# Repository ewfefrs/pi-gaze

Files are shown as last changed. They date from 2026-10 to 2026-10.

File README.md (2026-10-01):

# Pi-Gaze

Айтрекер на Raspberry Pi 5: ИК-камера над монитором следит за глазами, и курсор ПК идёт
туда, куда ты смотришь. Для ПК это обычная USB-мышь (CH9329), ставить на ПК ничего не нужно.

| Часть | Где | Проверка |
|---|---|---|
| Железо: тиски на монитор, бар с камерой и ИК-диодами, доработанный кейс Pi | [`hardware/`](hardware/README.md) | `hardware/check.sh` — контр-модель, 63 проверки |
| Программа: трекер глаз, калибровка, курсор | [`software/`](software/README.md) | `software/build_tests_windows.cmd` на ПК; на Pi тесты гоняет установщик |
| Решения и дизайн | [`docs/superpowers/specs/`](docs/superpowers/specs/) | — |

## Запуск с нуля

1. Напечатать и собрать железо: [`hardware/README.md`](hardware/README.md).
2. SD-карта: Raspberry Pi OS Lite 64-bit + файлы из `software/deploy/sdcard/` и папка
   `pigaze/` (= `software/`) в загрузочном разделе. Wi-Fi: вписать имя и пароль в
   `network-config` на карте (или подключить кабель).
3. Вставить карту, включить Pi. Первая загрузка сама соберёт и поставит программу и перезагрузится (~10 мин).
4. Сесть перед монитором и смотреть на курсор, пока идёт калибровка по 9 точкам. Дальше курсор
   следует за взглядом. Кнопка питания Pi: 1 нажатие — пауза, 2 нажатия — перекалибровка.

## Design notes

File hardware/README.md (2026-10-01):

# Pi-Gaze — железо (тиски + бар + готовый кейс RPi 5)

Айтрекер: Raspberry Pi 5 + Active Cooler + Camera Module 3 NoIR + 2 ИК-диода + CH9329.
Тиски садятся на верхнюю кромку монитора, бар с камерой — на шарнире сверху, готовый
кейс Pi висит «хвостом» прямо под задней губкой тисков.

**Проверено контр-моделью:** `./check.sh` → **63 проверки, 0 ошибок** (отчёт `check_report.txt`).

## Файлы

```
hardware/
  check.sh              полная пересборка + контр-модель (запускать это)
  check_pigaze.py       контр-модель (Python: trimesh + Manifold, реальный STL Pi 5)
  README.md             этот файл
  renders/              превью всех деталей и сборки (preview.py из cad-skill)
  enclosure/src/        OpenSCAD: clamp.scad (тиски), bar.scad (бар), pigaze.scad (сборка)
  enclosure/stl/        печатные детали pigaze_*.stl
  mount/case_mod.py     доработка ГОТОВОГО кейса (CadQuery + Manifold)
  mount/case_pigaze.stl, cover_pigaze.stl   кейс и крышка для печати
```
Старый кастомный бокс, его крышка, толкатель и старый чекер — в `enclosure/src/legacy/`,
`enclosure/stl/legacy/`; отклонённые «переходники» — в `mount/_obsolete/`. Ничего не удалено.

## Что было не так и что исправлено (аудит 2026-09-23)

Всё найдено измерениями по реальным STL (кейс, крышка, Pi 5 + кулер), не «на глаз».

| # | Ошибка | Исправление |
|---|---|---|
| 1 | Щель шлейфа в кейсе была на торце USB/Ethernet, а разъёмы CSI у Pi 5 — на ребре HDMI (X 5–14); щель к тому же **сливалась со средним USB-проёмом** | Щель — в SD-торце над кулером (Z 17.5–22.5), USB-проёмы не тронуты |
| 2 | Винты дока шли через дно под корпусами USB/RJ45 — **не подлезть** | Док — язычок на торце кейса, 2×M3 **сзади**, гайки в губке тисков |
| 3 | Кейс висел USB вверх: штекер (35–40 мм) упирался в маховик (13 мм) | Кейс висит **SD-торцом вверх**, USB/Ethernet смотрят вниз |
| 4 | **Передняя губа тисков не свисала** (`LIP_H = TOP_T`) — тиски не держали монитор | Губа свисает на 5 мм, мягкая прокладка по полосе контакта |
| 5 | В баре полость крыльев **срезала светоперегородки** ниже Z 15.5 (как раз на высоте ИК), а над крыльями они торчали 2-мм плавниками | Стенки отсека камеры — на всю высоту, плавники убраны |
| 6 | Бортики и прижимы крышки бара **не были сращены** с плитой (лишь касались) — висели отдельными телами | Заходят в плиту на 0.5 мм, деталь — одно тело |
| 7 | Глухая крышка кейса в 8 мм над турбиной кулера — **кулер задыхается** | Решётка в крышке над турбиной (4 щели 3×28) |
| 8 | Шлейф шёл открыто; щели бара 12 мм, а кабель Pi 5 — **16 мм** | Шлейф по прямой в закрытом тоннеле внутри губки + паз под крышкой; щель бара 16.4 мм |
| 9 | Гайка барашка в **полностью замкнутом** кармане — не вставить | Карман открыт на внутреннюю грань губки |
| 10 | Карман гайки дока заходил в скругление губки (стенка ~0.6 мм) | Винты дока перенесены внутрь (X 14.5 / 21.5) |
| 11 | Паузы для магнитов в README указывали **дно** кармана (15.6 / 0.8 мм) | Верные: бар **17.6 мм**, крышка бара **2.8 мм** |
| 12 | Спецификация/сборка/проверка описывали старый бокс (втулки M2.5, 16 магнитов, толкатель) | Всё переписано под готовый кейс |
| 13 | CH9329 остался без места | Люлька на боковой (GPIO) стенке кейса + щель под провода |
| 14 | Наши добавки к кейсу «висели» (стенка торца на X −47, а не −48) и не были герметичны | Врастают в стенку на 1 мм; финальный STL проверяется после перезагрузки |

## Печать

| Деталь | Файл | Материал | На стол | Пауза (магниты) |
|---|---|---|---|---|
| Тиски | `enclosure/stl/pigaze_clamp.stl` | PETG/ASA, 4 стенки, 35% | **на боку** (грань −X на стол), брим; поддержка-дерево только под тумбой шарнира и бобышкой барашка | — |
| Крышка паза шлейфа | `pigaze_ribbon_cover.stl` | PETG | плашмя | — |
| Бар | `pigaze_bar.stl` | **чёрный** PETG | оптикой вниз | **17.6 мм** — 4 магнита |
| Крышка бара | `pigaze_bar_lid.stl` | **чёрный** PETG | наружной гранью вниз | **2.8 мм** — 4 магнита |
| Маховик Ø20 | `pigaze_knob.stl` | PETG | плашмя | — |
| Пятка | `pigaze_foot.stl` | TPU / PETG | площадкой вниз | — |
| Прокладка губы | `pigaze_pad.stl` | **TPU** | плашмя | — |
| Кейс | `mount/case_pigaze.stl` | PETG/ASA | **дном вниз** (как оригинал) | — |
| Крышка кейса | `mount/cover_pigaze.stl` | PETG/ASA | наружной гранью вниз | — |

* Тиски — **не PLA** (постоянная нагрузка, ползучесть). На боку тоннель и паз печатаются без поддержек.
* Кейс: все добавки стоят на плоскости стола или на откосах ≤50° — поддержки не нужны.
* Бар — только **чёрный** пластик: стенки не должны отражать ИК.
* Магниты: на паузе кладёшь в открытые карманы, печать их замуровывает. Полярность
  бар/крышка — противоположная, пометь маркером заранее.

## Закупка

| Позиция | Кол-во | Куда |
|---|---|---|
| Болт **M3×40** DIN933 (шестигр. головка) | 1 | барашек (головка в маховике) |
| Винт **M3×30** | 1 | ось шарнира + фиксация угла |
| Винт **M3×12** DIN912 (внутр. шестигр.) | 2 | док: язычок кейса → губка тисков |
| Винт **M3×6** (не длиннее! иначе конец упрётся в монитор) | 2 | крышка паза шлейфа |
| Гайка **M3** DIN934 | 6 | барашек 1 · шарнир 1 · док 2 · крышка паза 2 |
| Винт **M2.5×8** + гайка M2.5 | 4 + 4 | Pi → стойки кейса (гайки в шестигр. гнёзда снизу) |
| Магнит N42 **5×2 мм** | 8 | бар 4 + крышка бара 4 |
| Кабель камеры **Pi 5, 22→15 pin, 200 мм** (300 мм тоже влезет — излишек сложить под крышкой) | 1 | маршрут ≈163 мм |

Электроника: Pi 5 + Active Cooler · Camera Module 3 **NoIR** · 2× Vishay TSHA5203 (875 нм) +
2× 180 Ω + ключ-транзистор (диоды от 5 В, **не** напрямую от GPIO; база через ~1 кОм на
**GPIO18**, контакт 12 — им управляет программа) · модуль CH9329. Распиновка — в
[`software/README.md`](../software/README.md#подключение-pi-5-40-pin).

## Сборка

1. **Гайки:** в тисках — гайка барашка и 2 гайки дока в карманы на **внутренней** грани
   задней губки; 2 гайки крышки паза — снизу в карманы перемычки, **вдавить до упора вверх**; гайка шарнира — в правую щёку вилки бара.
2. **Pi в кейс** (4× M2.5×8 + гайки снизу). Кабель камеры узким концом (22 pin) — в CAM/DISP.
3. **Шлейф внутри:** плоско вдоль стороны HDMI к SD-торцу, над кулером (под крышкой ~7 мм зазора),
   и наружу через щель в торце. Провода ИК — рядом со шлейфом.
4. **Вверх по губке:** широкий конец кабеля продеть снизу в тоннель задней губки — он прямой,
   48 мм, выходит на верх перемычки.
5. **Док:** кейс язычком к наружной грани губки, 2× M3×12 **сзади** шестигранником через колодцы.
   Кейс снимается так же сзади, не снимая тиски.
6. Шлейф — в паз по верху перемычки, сверху **крышка паза** (2× M3×6; гайки снизу вталкиваются вверх до упора).
7. **Бар:** камера в карман, шлейф снизу через центральную щель в разъём камеры; ИК-диоды в
   колодцы, провода — через отверстия в стенке отсека; крышка бара на магнитах.
8. **Шарнир:** вилка бара на кулак, M3×30 + гайка, выставить угол (рабочий −20…−48°), затянуть.
9. **CH9329** в люльку на боку кейса; 4 провода от GPIO (контакты 1–10, со стороны SD) через щель.
   ⚠ Линии UART к Pi — только **3.3 В** (питай модуль от 3.3 В или ставь преобразователь уровней).
10. Крышка кейса на защёлку — решёткой к турбине кулера.
11. **На монитор:** передняя губа с TPU-прокладкой за переднюю рамку (≥5 мм рамки сверху),
    барашком прижать пятку к задней стенке.

## Контр-модель (`./check.sh`)

Пересобирает кейс, экспортирует все детали и позы и пытается доказать, что сборка плохая.
Последний прогон — **63/63**:

- **A** каждая деталь герметична и состоит из **одного** тела (ничего не «висит»);
- **B** попарные пересечения всех деталей в собранном виде — нет;
- **C** реальный Pi 5 + кулер внутри кейса/крышки — только посадка платы на стойки; выше всего
  стек USB (Z 21.6) — 2.4 мм до крышки;
- **D** «призрак» шлейфа 16.2 мм по всему маршруту (кейс → щель → воротник → тоннель → паз →
  подъём → щель бара) ни за что не задевает, в том числе за реальный Pi;
- **E** монитор 15 мм входит; губа реально цепляет рамку;
- **F** бар с крышкой на −20/−30/−38/−48° не задевает тиски, крышку паза, её винты, маховик, кейс;
- **G** маховик в крайних положениях не задевает кейс; место для пальцев 8.1 / 15 мм;
- **H** свободны штекеры RJ45, 2×USB, USB-C, 2×micro-HDMI, доступ к microSD и рычагу кнопки питания;
- **I** отверстия дока совпадают с гайками губки до 0.01 мм; щель кейса — в створе тоннеля;
  шарнир — на линии шлейфа;
- **J** щупы: стенки отсека бара на высоте ИК, нет плавников, карманы гаек доступны, тоннель сквозной;
- **K** зазор решётки кулера до монитора 15.5 мм; длина кабеля;
- **L** крепёж: конец винта крышки паза (M3×6) остаётся внутри перемычки (Z 1.0 над монитором), гайка
  навинчена на всю высоту; винты дока M3×12 проходят гайку губки и не достают до монитора.

## Что проверить на месте

* **Размер CH9329** — люлька под 34×15×9 мм (`CH_*` в `case_mod.py`), у модулей бывает иначе.
* **Рамка монитора** сверху ≥5 мм (губа свисает на 5 мм); толщина кромки — до ~27 мм.
* Какой разъём CAM/DISP используешь — неважно, маршрут общий.

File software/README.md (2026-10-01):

# Pi-Gaze — программа

Глаза двигают курсор ПК. Raspberry Pi 5 смотрит на глаза через ИК-камеру на баре, понимает,
куда на экране ты смотришь, и двигает мышь ПК через CH9329 (для ПК это обычная USB-мышь).
На ПК ничего ставить не надо.

Архитектура и решения: [`docs/superpowers/specs/2026-09-25-pigaze-software-design.md`](../docs/superpowers/specs/2026-09-25-pigaze-software-design.md).

## Как пользоваться

| Действие | Что происходит |
|---|---|
| Первое включение | Pi сам собирает и ставит программу (~5–10 мин, нужен интернет), перезагружается |
| Сел перед монитором | через 2 с видимых глаз стартует **калибровка**: курсор по очереди встаёт в 9 точек — **смотри на курсор** (~19 с) |
| Удачная калибровка | курсор описывает кружок в центре; дальше курсор ходит за взглядом |
| Неудачная | курсор «трясёт головой» влево-вправо; старая калибровка остаётся |
| Кнопка питания Pi, **1 нажатие** | пауза / продолжить (в паузе мышь снова твоя) |
| Кнопка питания, **2 нажатия** | перекалибровка (сдвинулся, пересел, сменил освещение) |
| Кнопка питания, **держать** | выключение Pi |

Моргание и взгляд мимо экрана курсор не дёргают — он просто стоит. Клик взглядом
(задержка на месте 1,2 с) выключен по умолчанию: `dwell_click = 1` в конфиге.

## С ПК по SSH

```bash
ssh -i ~/.ssh/pigaze_ed25519 -L 8080:localhost:8080 pigaze@pigaze.local
```

Пока сессия открыта, отладочная страница — <http://localhost:8080>: живой ИК-кадр
(жёлтое — окна глаз, красное — зрачок, зелёное — блики диодов), увеличенные глаза,
состояние и кнопки «Калибровка» / «Пауза». Страница слушает только localhost Pi,
потому что показывает твоё лицо.

На Pi:

```bash
journalctl -u pigaze -f            # лог: к/с, % кадров с глазами, режим, взгляд
pigaze-ctl calibrate               # toggle | pause | resume
sudo nano /etc/pigaze/pigaze.conf  # настройки, затем: sudo systemctl restart pigaze
pigaze --snapshot /tmp/f.pgm       # один кадр с камеры (при остановленной службе)
pigaze --selftest                  # проверка трекера на синтетике, без камеры
```

Пароля у пользователя `pigaze` нет — вход только по SSH-ключу. Нужен пароль для
консоли: `sudo passwd pigaze`.

## Настройка по месту

* **Фокус.** `lens_position = 1.7` — это 60 см (диоптрии = 1 / метры). Сидишь на 50 см → 2.0,
  на 70 см → 1.4. Смотри на увеличенные глаза на отладочной странице: зрачок должен быть резким.
* **Экспозиция.** По умолчанию авто. Если блики не белые или зрачок не чёрный:
  `shutter_us = 8000`, `gain = 4` и подстрой.
* **Очки** дают большие блики; они отфильтровываются (`glint_max_area`), но могут закрыть зрачок.
  Помогает наклон бара, чтобы отражение ушло вбок.
* **Курсор дрожит** → уменьши `filter_min_cutoff` (0.4). **Отстаёт** → увеличь `filter_beta` (3–4).

## Сборка и тесты

На Pi это делает установщик (`deploy/pi-setup.sh`): ставит `g++`, если нет, собирает, гоняет
модульные тесты и `--selftest`, ставит службу. Повторный запуск безопасен:

```bash
sudo bash /opt/pigaze/src/deploy/pi-setup.sh
```

На Windows-ПК (MSVC из Visual Studio) собираются и проверяются переносимые модули:

```bash
software/build_tests_windows.cmd
```

## Устройство

```
include/pigaze/, src/core/   переносимое ядро (тестируется на ПК и на Pi)
  eye_detector   зрачок (тёмный) + блики ИК-диодов в окне глаза, субпиксельный центр
  tracker        поиск пары глаз по бликам во всём кадре, слежение, моргания
  gaze           вектор «зрачок - блик» / межзрачковое расстояние -> полином 2-й степени
  calibration    9 точек курсором, медианы, проверка RMS
  filter         One Euro (без дрожи на фиксации, без задержки на скачках), dwell
  controller     режимы: нужна калибровка / калибровка / слежение / пауза
  ch9329         кадры протокола CH9329, абсолютная мышь 0..4095
  config, debugview, synth, image, linalg
src/linux/        rpicam-vid (кадры через pipe), UART, кнопка питания, FIFO, HTTP
src/main.cpp      сборка всего в цикл
deploy/           systemd-службы, установщик, logind (кнопка питания), pigaze-ctl
```

## Подключение (Pi 5, 40-pin)

| Pi | Куда |
|---|---|
| pin 1 (3.3 V) | CH9329 VCC (модуль на 3.3 В — тогда и его TX 3.3 В, безопасно для Pi) |
| pin 6 (GND) | CH9329 GND |
| pin 8 (GPIO14, TX) | CH9329 **RX** |
| pin 10 (GPIO15, RX) | CH9329 **TX** |
| pin 12 (GPIO18) | база ключ-транзистора ИК-диодов (через ~1 кОм) |
| pin 2/4 (5 V) | питание ИК-диодов через 180 Ω |

USB CH9329 — в ПК. Камера — в любой из разъёмов CAM/DISP.

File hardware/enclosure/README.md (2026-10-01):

# Pi-Gaze enclosure (OpenSCAD part of the hardware)

See **../README.md** (build, print, BOM, assembly) and run **../check.sh** (full rebuild + counter-model).
The retired custom-box design and its old README live in `src/legacy/`.

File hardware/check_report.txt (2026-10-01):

[A] printable parts: watertight + one solid body
  PASS  A clamp                                        watertight=True solids=1
  PASS  A ribbon_cover                                 watertight=True solids=1
  PASS  A pad                                          watertight=True solids=1
  PASS  A foot                                         watertight=True solids=1
  PASS  A knob                                         watertight=True solids=1
  PASS  A bar                                          watertight=True solids=1
  PASS  A bar_lid                                      watertight=True solids=1
  PASS  A case                                         watertight=True solids=1
  PASS  A cover                                        watertight=True solids=1

[B] pairwise interference (assembled, bar at -38 deg)
  PASS  B bar <-> bar_lid                              overlap 0.000 mm3
  PASS  B case<->cover (stock snap fit)                INFO overlap 0.00 mm3 (original cover design)
  PASS  B all other pairs                              no overlap

[C] real Pi 5 + Active Cooler inside the modified case / cover
  PASS  C Pi vs case (excl. PCB-on-standoff contact)   3 pts inside (437 standoff contact)
  PASS  C Pi vs cover                                  0 pts inside
  PASS  C tallest Pi part under the cover              top Z 21.62, cover underside 24.03

[D] ghost camera ribbon (16.2 mm) along the full route
  PASS  D ribbon: inside case -> slot -> collar -> jaw tunnel worst: clamp 0.000 mm3
  PASS  D ribbon: bridge-top groove (under cover)      worst: clamp 0.000 mm3
  PASS  D ribbon: free rise to the bar                 worst: clamp 0.000 mm3
  PASS  D ribbon: through the bar floor slot (bar -38 deg) worst: clamp 0.000 mm3
  PASS  D ribbon run under the cover vs real Pi        0 Pi points in the ribbon's path
  PASS  K camera cable route length                    163 mm -> use the 200 mm Pi 5 camera cable (300 mm also fits, fold slack under the cover)

[E] monitor fit (top edge 15 mm)
  PASS  E monitor <-> clamp                            overlap 0.000 mm3
  PASS  E monitor <-> pad                              overlap 0.000 mm3
  PASS  E monitor <-> foot                             overlap 0.000 mm3
  PASS  E monitor <-> case                             overlap 0.000 mm3
  PASS  E monitor <-> cover                            overlap 0.000 mm3
  PASS  E monitor <-> ribbon_cover                     overlap 0.000 mm3
  PASS  E monitor <-> knob                             overlap 0.000 mm3
  PASS  E front lip hangs below the monitor top        lip bottom Z -5.0 (monitor top at 0)

[F] hinge sweep -20..-48 deg
  PASS  F bar+lid at -20 deg                           worst: - 0.000 mm3
  PASS  F bar+lid at -30 deg                           worst: - 0.000 mm3
  PASS  F bar+lid at -38 deg                           worst: - 0.000 mm3
  PASS  F bar+lid at -48 deg                           worst: - 0.000 mm3

[G] thumbscrew knob travel
  PASS  G knob at Y=31 vs case/bar                     overlap 0.000 mm3
  PASS  G finger room knob(Y=31) -> case               min gap 8.2 mm (need 7)
  PASS  G knob at Y=45 vs case/bar                     overlap 0.000 mm3
  PASS  G finger room knob(Y=45) -> case               min gap 15.0 mm (need 10)
  PASS  G thumbscrew bolt vs case/cover                

[H] access: plugs, card, button
  PASS  H RJ45 plug (down) free                        blocked 0.000 mm3
  PASS  H USB stack 1 plug free                        blocked 0.000 mm3
  PASS  H USB stack 2 plug free                        blocked 0.000 mm3
  PASS  H USB-C power plug free                        blocked 0.000 mm3
  PASS  H micro-HDMI 0 plug free                       blocked 0.000 mm3
  PASS  H micro-HDMI 1 plug free                       blocked 0.000 mm3
  PASS  H microSD fingernail free                      blocked 0.000 mm3
  PASS  H power-button lever free                      blocked 0.000 mm3

[I] interfaces
  PASS  I dock hole case(-58,11.0) -> jaw nut X14      maps to X 14.50 Z -36.00
  PASS  I dock hole case(-58,18.0) -> jaw nut X22      maps to X 21.50 Z -36.00
  PASS  I case ribbon slot within jaw tunnel X         slot X -25.0..-8.0 / tunnel -25.5..-7.5
  PASS  I ribbon slot straddles tunnel Y               slot Y 18.0..23.0 / tunnel 19.0..22.0
  PASS  I hinge on the ribbon line                     hinge X -16.5

[J] probes
  PASS  J bar: compartment wall at IR height (+/-18.3,0,9) 
  PASS  J bar: no external fins (+/-20.5,0,22)         
  PASS  J thumbscrew nut pocket reachable from monitor side 
  PASS  J dock 1 nut pocket reachable from monitor side 
  PASS  J dock 2 nut pocket reachable from monitor side 
  PASS  J ribbon tunnel open bottom->top               

[L] fasteners: screw tips vs monitor, nut engagement
  PASS  L cover screw M3x6 tip stays inside the bridge tip Z 1.0 (monitor top at 0)
  PASS  L cover screw fully through its nut            engaged 2.4 / 2.4 mm
  PASS  L cover nut pocket reachable from below        
  PASS  L dock screw M3x12 through the jaw nut         tip Y 15.7, nut Y 17.0-19.4
  PASS  L dock screw tip clear of a 27 mm monitor      tip Y 15.7 vs monitor back Y 10.0

[K] cooling
  PASS  K fan-grille -> monitor back air gap           15.5 mm

COUNTER-MODEL CLEAN: 63 checks, 0 failures

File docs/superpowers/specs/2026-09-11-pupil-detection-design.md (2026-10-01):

# Pi-Gaze — Module 1: Pupil Detection (design)

- **Date:** 2026-09-11
- **Status:** SUPERSEDED by `2026-09-25-pigaze-software-design.md` (OpenCV + toolchain does not
  fit the 3.7 GB SD card; the IR glints make a face DNN unnecessary)
- **Author:** Claude (with user)

## Goal

Produce a reliable **per-frame pupil center (x, y) for each eye** from a remote,
monitor-mounted IR camera, verifiable **headless over SSH**. This is the input
foundation for later gaze mapping — it does not itself move a cursor.

## Context & constraints

- **Hardware:** Raspberry Pi 5, Camera Module 3 **NoIR**, IR illuminators, mounted
  on the bar at the monitor's top edge, tilted down at the user's face.
- **Geometry:** *remote* — the whole face is in frame at ~40–70 cm. So we must
  localize face → eyes **before** looking for the pupil (the pupil is only a few
  pixels wide at this distance).
- **Illumination:** IR (NoIR sensor + IR LEDs) gives a **dark-pupil** signal and
  bright **corneal glints** from the LEDs.
- **Software:** C++17 (real-time perf), OpenCV, Raspberry Pi OS Lite 64-bit
  (Bookworm), headless. Pi 5 camera stack is **libcamera** (not legacy V4L2).

## Scope

**In:** camera capture; face + eye localization; pupil center per eye; glint
position; per-result confidence; headless verification (annotated frame dump +
optional MJPEG stream); a small config file; FPS logging.

**Out (later modules, not now):** gaze mapping & calibration; CH9329 USB-HID mouse
output; control-loop smoothing/filtering; multi-user; auto IR power control.

## Architecture (units, each independently testable)

1. **Camera** — opens the Camera Module 3 through libcamera and yields grayscale
   `cv::Mat` frames. Path: OpenCV `VideoCapture` with the **GStreamer**
   `libcamerasrc` pipeline (`libcamerasrc ! video/x-raw ! videoconvert ! appsink`),
   the clean C++ route on Pi 5. Exposes manual exposure/gain for IR tuning.
2. **FaceEyes** — runs OpenCV's built-in **YuNet** DNN face detector
   (`cv::FaceDetectorYN`, mainline objdetect since 4.5.4). YuNet returns the face
   box **plus 5 landmarks including both eye centers**, so we get eye ROIs with no
   separate eye cascade and no heavy landmark model. Emits `std::vector<Eye>`.
3. **PupilDetector** — within an eye ROI: normalize → adaptive threshold on the
   **dark-pupil** region → contour extraction → filter by area/circularity →
   **ellipse fit** for a sub-pixel center; separately take the brightest spot as
   the IR **glint**. Emits a `PupilResult`.
4. **Telemetry/Verify** — a `PupilResult` sink: structured log (coords, radius,
   confidence, FPS), annotated-frame writer (JPEG to disk), and an optional MJPEG
   HTTP server so the result can be watched in a browser over SSH.
5. **Config** — a small file (key=value or minimal JSON): camera resolution/fps,
   exposure/gain, threshold/ROI-scale, output mode. Sane defaults if absent.
6. **App loop** — wires Camera → FaceEyes → PupilDetector → Telemetry; clean
   startup/shutdown, signal handling.

## Interfaces (sketch)

```cpp
struct PupilResult {
    cv::Point2f center;        // in full-frame coordinates
    float       radius;        // px (ellipse minor/major avg)
    float       confidence;    // 0..1
    std::optional<cv::Point2f> glint;
    bool        valid;
};
struct Eye { cv::Rect roi; cv::Point2f center; bool isLeft; };

class Camera        { public: bool open(const Config&); bool next(cv::Mat& gray); };
class FaceEyes      { public: bool load(const std::string& model); std::vector<Eye> detect(const cv::Mat& gray); };
class PupilDetector { public: PupilResult detect(const cv::Mat& gray, const Eye& eye); };
```

## Data flow

`frame → FaceEyes.detect → per-eye ROI → PupilDetector.detect → PupilResult[] → Telemetry`

## Error handling

- Camera/GStreamer open fails → clear message, non-zero exit.
- No face this frame → emit "no face", keep running (don't crash/stall).
- Low-confidence or no pupil → `valid=false`; never emit a garbage coordinate.
- Missing config → defaults; malformed config → warn + defaults for bad keys.

## Verification (headless, over SSH)

- **Golden test:** a handful of recorded IR eye frames are checked into
  `test/data/` with hand-labeled pupil centers; the detector must land within a
  pixel tolerance. Runs in CI-style `ctest` with no camera attached.
- **Live check:** annotated-frame dump + FPS counter; optional MJPEG to eyeball it
  in a browser.
- **Success criteria:** on a cooperative user at ~60 cm, pupil center jitter
  **< ~3 px** frame-to-frame, **≥ 15 FPS** at the chosen resolution, and graceful
  "no face"/`valid=false` handling when the eye is occluded or absent.

## Build & deploy

- **CMake** project under `pi-gaze/software/`. Dependencies from apt on Bookworm:
  `libopencv-dev` (has DNN + GStreamer), `gstreamer1.0-libcamera`,
  `libcamera-dev`. YuNet `.onnx` model vendored under `software/models/`.
- Build **on the Pi** (needs a **≥16 GB** card — the current 3.7 GB card fits the
  OS but not OpenCV + toolchain) or cross-compile. First bring-up can validate raw
  capture with `rpicam-hello` before OpenCV is present.

## Assumptions / open items (safe defaults chosen)

- Resolution/FPS start at **1280×720 @ 30**; revisit if the pupil is too small.
- Detect **both** eyes; downstream picks the higher-confidence one.
- IR exposure/gain set **manually** in config for v1 (no auto control yet).

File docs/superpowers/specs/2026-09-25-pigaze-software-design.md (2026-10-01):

# Pi-Gaze — software v1 (design)

- **Date:** 2026-09-25
- **Status:** approved by delegation ("продумай логику сам, доводи до ума")
- **Supersedes:** `2026-09-11-pupil-detection-design.md` (OpenCV + YuNet) — see "Why not OpenCV".

## Goal

Eyes move the PC cursor. The Pi watches the user's eyes through the IR camera on the
bar, estimates where on the screen they look, and moves the PC's mouse through the
CH9329 (USB HID). No software on the PC.

## Why not OpenCV (change from the 09-11 spec)

The only SD card is **3.7 GB**; Pi OS Lite 64-bit (Trixie) takes 3.06 GB, leaving ~0.9 GB.
OpenCV-dev + GStreamer + toolchain does not fit. The IR setup gives a much cheaper eye
finder than a face DNN: **corneal glints** (reflections of our own IR LEDs) are the
brightest tiny spots in the frame and each sits right next to a **dark pupil**. So the
whole pipeline is plain C++17 with no third-party libraries:

- camera frames come from `rpicam-vid --codec yuv420 -o -` (preinstalled rpicam-apps),
  we read the Y plane from the pipe;
- detection, calibration, filtering, HID, debug web page — our own code;
- the portable core (everything except camera/serial/button/http) builds and is
  unit-tested on the Windows PC with MSVC, and again on the Pi with g++ before install.

## Pipeline

```
rpicam-vid (Y plane) -> EyeTracker -> features -> GazeModel -> OneEuro -> Controller -> CH9329 -> PC cursor
                         |  finder: glint + dark pupil, pairs by IPD
                         |  tracker: per-eye ROI around last pupil
```

1. **EyeDetector** (per eye ROI): median/threshold -> glint blobs (small, bright) ->
   inpaint glints -> darkest seed (with distance penalty) -> region grow with an adaptive
   pupil/iris threshold (2 passes) -> moments -> radial edge points -> ellipse fit
   (fallback circle, fallback centroid) -> confidence. Glint = intensity-weighted centroid
   of the small bright blobs near the pupil (the two LED reflections are < 3 px apart at
   60 cm, so they are treated as one reference point).
2. **EyeFinder** (full frame, only when not tracking): bright small blobs with local
   contrast -> run EyeDetector around each -> dedupe -> choose the best **pair** whose
   distance fits the IPD range and is roughly horizontal. Initial acquisition requires a
   pair (so slot 0 = image-left eye, slot 1 = image-right eye is unambiguous).
3. **EyeTracker**: per slot ROI tracking; blink tolerance (`lost_frames`); re-acquires a
   single lost eye from the other eye + last inter-eye offset; full search when both lost.
   Keeps a smoothed IPD in px (head-distance scale).
4. **Feature** per eye: `(pupil - glint) * 100 / IPD_px` — pupil-centre/corneal-reflection
   vector normalised by head distance.
5. **GazeModel**: per eye 2nd-order polynomial (6 terms per axis, ridge LS; affine if < 6
   points), inputs normalised. Prediction = confidence-free mean of the valid eyes.
   Saved to `/var/lib/pigaze/calibration.txt`.
6. **Calibration without a PC app**: the Pi itself puts the cursor (CH9329 absolute mode)
   on 9 points (3x3, 10 % margin), wiggles it briefly to catch the eye, waits for the
   saccade to settle, collects ~1 s of features, takes per-point medians, fits, checks
   RMS. Success -> cursor draws a small circle; failure -> cursor shakes, old calibration
   is kept.
7. **Filtering**: One Euro filter (low jitter on fixations, low lag on saccades); cursor
   held still when no valid gaze (blink, looking away). Optional dwell click (off).
8. **Controller** modes: `NeedCalibration -> Calibrating -> Tracking <-> Paused`.
   Inputs: Pi 5 **power button** (logind told to ignore it): single press = pause/resume
   (or start calibration if none), double press = recalibrate; long press stays
   "power off" (logind `HandlePowerKeyLongPress=poweroff`). Also a FIFO
   `/run/pigaze/control` (`pigaze-ctl calibrate|toggle|pause|resume`) and the debug page.
   Auto-calibration on first run once eyes are seen for 2 s.
9. **CH9329**: UART0 on GPIO14/15 (`/dev/ttyAMA0`, 9600 8N1, `dtparam=uart0=on`),
   absolute mouse frames `57 AB 00 04 07 02 btn xl xh yl yh wh sum`, 0..4095 range.
   Moves are dropped (not queued) if the UART still has > 2 frames pending -> no lag build-up.
10. **Debug page** (`http_bind:http_port`, default `127.0.0.1:8080`, reach via
    `ssh -L 8080:localhost:8080`): live downscaled IR frame + eye zooms with the pupil/glint
    overlay (BMP, no encoder needed), JSON status, Calibrate / Pause buttons. Localhost by
    default because it shows the user's face.

## Files

```
software/
  include/pigaze/*.hpp      src/core/*.cpp   (portable, unit-tested on PC and Pi)
  src/linux/*.cpp  src/main.cpp              (rpicam pipe, termios, input, http, fifo)
  tests/*.cpp                                (own tiny harness, no downloads)
  config/pigaze.conf   deploy/ (systemd units, installer, logind drop-in, pigaze-ctl)
  CMakeLists.txt  build_tests_windows.cmd
```

## Deploy

SD card: Pi OS Lite 64-bit Trixie; cloud-init `user-data` creates user `pigaze`
(SSH **key only**, no password), hostname `pigaze`, enables SSH; `config.txt` gets
`dtparam=uart0=on`; the source is copied to the boot partition. On first boot a oneshot
service (retried every boot until it succeeds, needs network for `apt install g++`)
builds + runs the tests on the Pi, installs `/usr/local/bin/pigaze`, the config, the
service and the logind drop-in, then reboots once. Wi-Fi: the user types SSID/password
into `network-config` themselves, or plugs Ethernet.

## Error handling

- Camera missing / rpicam-vid exits -> logged, restarted every 3 s; service keeps running.
- CH9329 missing -> logged once; tracking still runs (debug page works), retried every 5 s.
- No eyes / low confidence -> no cursor movement, never a garbage coordinate.
- Bad config keys -> warning + default.

## Verification

- PC: `software/build_tests_windows.cmd` (MSVC) — detector accuracy on synthetic IR eyes
  (sub-pixel centre, glint on the pupil edge, eyelid, noise, no-eye rejection), finder
  on a synthetic face with distractors, tracker through a blink, polynomial fit,
  calibration session, One Euro, dwell, CH9329 bytes, config, controller modes, BMP.
- Pi: installer compiles and runs the same tests before installing; `pigaze --selftest`
  runs the synthetic scene through the live binary; `pigaze --snapshot f.pgm` grabs a
  real frame for tuning; debug page for live checks.

## Known limits (v1)

- Accuracy is that of a single-camera PCCR tracker: expect ~1–2 deg (1–2 cm at 60 cm);
  moving the head a lot calls for recalibration (double press).
- Absolute HID maps to the primary monitor on Windows.
- Glasses reflections: large bright blobs are ignored as glints, but can hide the pupil.

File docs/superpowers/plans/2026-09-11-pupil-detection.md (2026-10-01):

# Pupil Detection (Module 1) Implementation Plan

> **SUPERSEDED (2026-09-25):** not executed. Replaced by the dependency-free implementation in
> `software/` — see `docs/superpowers/specs/2026-09-25-pigaze-software-design.md`.

> **For agentic workers:** REQUIRED SUB-SKILL: Use superpowers:subagent-driven-development (recommended) or superpowers:executing-plans to implement this plan task-by-task. Steps use checkbox (`- [ ]`) syntax for tracking.

**Goal:** Detect a per-frame pupil center (x, y) for each eye from a remote, monitor-mounted IR camera, verifiable headless over SSH.

**Architecture:** A small C++17/CMake project under `pi-gaze/software/`. A `pigaze_core` library exposes independent units — Config, PupilDetector, Telemetry, FaceEyes, Camera — wired by a thin `pigaze` app. The pipeline is Camera → FaceEyes (YuNet) → PupilDetector (IR dark-pupil ellipse fit) → Telemetry. Camera-independent units are built and unit-tested first on any Linux dev box; the camera unit is brought up on the Pi.

**Tech Stack:** C++17, CMake, OpenCV (`libopencv-dev`, uses `objdetect`/`FaceDetectorYN`, `imgproc`, `dnn`, GStreamer capture), doctest (vendored single header), libcamera via OpenCV's GStreamer `libcamerasrc` backend.

## Global Constraints

- Language **C++17**; build **CMake ≥ 3.16**; compiler **g++ ≥ 10** or clang.
- **OpenCV ≥ 4.5.4** with `objdetect` (for `cv::FaceDetectorYN`), `imgproc`, `dnn`, and **GStreamer** capture — install via `apt install libopencv-dev` on Debian **Bookworm** (the Pi) or Ubuntu (a **WSL2** dev box; native Windows C++ OpenCV is out of scope).
- Test framework: **doctest**, vendored at `software/third_party/doctest.h`; one test binary `pigaze_tests` registered with **CTest**.
- All pupil/glint coordinates are in **full-frame pixel space** unless a signature says ROI-local.
- Camera capture uses **libcamera** through OpenCV `VideoCapture(pipeline, cv::CAP_GSTREAMER)` — never legacy V4L2.
- **TDD**: every unit lands with its failing test first. **Commit after every green step.**
- Build/run on the Pi needs a **≥ 16 GB** SD card (OpenCV + toolchain); the 3.7 GB card is OS-only.

## File Structure

```
software/
  CMakeLists.txt              # top-level: core lib + app + tests
  third_party/doctest.h       # vendored single-header test framework
  include/pigaze/
    types.hpp                 # PupilResult, Eye (POD, no logic)
    config.hpp                # Config struct + load()
    pupil_detector.hpp        # PupilDetector
    telemetry.hpp             # Telemetry (log/annotate/writeFrame)
    face_eyes.hpp             # FaceEyes (YuNet)
    camera.hpp                # Camera (libcamera/GStreamer)
  src/
    config.cpp
    pupil_detector.cpp
    telemetry.cpp
    face_eyes.cpp
    camera.cpp
    main.cpp                  # app loop
  models/                     # face_detection_yunet_2023mar.onnx (vendored)
  test/
    test_types.cpp
    test_config.cpp
    test_pupil_detector.cpp
    test_telemetry.cpp
    test_golden.cpp
    test_face_eyes.cpp
    fixtures.hpp              # synthetic-image helpers shared by tests
    data/                     # golden frames + labels, a test face image
  config.example.ini
```

Tasks 1–5 build and test with **no camera** (any Linux/WSL2). Task 6 needs the YuNet model + a face image (still no camera). Tasks 7–8 need the Pi + camera.

---

### Task 1: Project scaffold, types, and a green CTest

**Files:**
- Create: `software/CMakeLists.txt`, `software/third_party/doctest.h` (download), `software/include/pigaze/types.hpp`, `software/test/test_types.cpp`
- Test: `software/test/test_types.cpp`

**Interfaces:**
- Produces: `pigaze::PupilResult { cv::Point2f center; float radius; float confidence; std::optional<cv::Point2f> glint; bool valid; }` and `pigaze::Eye { cv::Rect roi; cv::Point2f center; bool isLeft; }`.

- [ ] **Step 1: Vendor doctest**

Run: `curl -L -o software/third_party/doctest.h https://raw.githubusercontent.com/doctest/doctest/v2.4.11/doctest/doctest.h`
Expected: file ~230 KB exists.

- [ ] **Step 2: Write the failing test**

`software/test/test_types.cpp`:
```cpp
#include "doctest.h"
#include "pigaze/types.hpp"

TEST_CASE("PupilResult default is invalid") {
    pigaze::PupilResult r;
    CHECK(r.valid == false);
    CHECK_FALSE(r.glint.has_value());
}
TEST_CASE("Eye holds an ROI and a side flag") {
    pigaze::Eye e{ cv::Rect(1, 2, 3, 4), cv::Point2f(2.5f, 4.0f), true };
    CHECK(e.roi.width == 3);
    CHECK(e.isLeft);
}
```

- [ ] **Step 3: Write `CMakeLists.txt` (core lib + tests)**

`software/CMakeLists.txt`:
```cmake
cmake_minimum_required(VERSION 3.16)
project(pigaze LANGUAGES CXX)
set(CMAKE_CXX_STANDARD 17)
set(CMAKE_CXX_STANDARD_REQUIRED ON)
find_package(OpenCV REQUIRED)
enable_testing()

add_library(pigaze_core)           # sources added by later tasks
target_include_directories(pigaze_core PUBLIC include ${OpenCV_INCLUDE_DIRS})
target_link_libraries(pigaze_core PUBLIC ${OpenCV_LIBS})
set_target_properties(pigaze_core PROPERTIES LINKER_LANGUAGE CXX)

add_executable(pigaze_tests
    test/test_types.cpp)
target_include_directories(pigaze_tests PRIVATE third_party include)
target_link_libraries(pigaze_tests PRIVATE pigaze_core)
add_test(NAME pigaze_tests COMMAND pigaze_tests)
```
Add a doctest main once, at the top of `test/test_types.cpp`:
```cpp
#define DOCTEST_CONFIG_IMPLEMENT_WITH_MAIN
```
(placed above the existing `#include "doctest.h"`).

`pigaze_core` needs at least one source to link; add a placeholder now and replace in Task 2:
```cmake
target_sources(pigaze_core PRIVATE src/placeholder.cpp)
```
Create `software/src/placeholder.cpp` with `namespace pigaze { int _link_stub = 0; }`.

- [ ] **Step 4: Write `types.hpp`**

`software/include/pigaze/types.hpp`:
```cpp
#pragma once
#include <optional>
#include <opencv2/core.hpp>
namespace pigaze {
struct PupilResult {
    cv::Point2f center{};
    float radius{0.f};
    float confidence{0.f};
    std::optional<cv::Point2f> glint{};
    bool valid{false};
};
struct Eye {
    cv::Rect roi{};
    cv::Point2f center{};
    bool isLeft{false};
};
}  // namespace pigaze
```

- [ ] **Step 5: Configure, build, run — expect PASS**

Run: `cmake -S software -B software/build && cmake --build software/build -j && ctest --test-dir software/build --output-on-failure`
Expected: `pigaze_tests` PASS (2 test cases).

- [ ] **Step 6: Commit**
```bash
git add software/ && git commit -m "feat(sw): scaffold CMake+doctest, core types"
```

---

### Task 2: Config loader

**Files:**
- Create: `software/include/pigaze/config.hpp`, `software/src/config.cpp`, `software/config.example.ini`, `software/test/test_config.cpp`
- Modify: `software/CMakeLists.txt` (add `src/config.cpp` to `pigaze_core`, delete the placeholder; add `test/test_config.cpp` to `pigaze_tests`)

**Interfaces:**
- Consumes: nothing.
- Produces: `struct Config { int width=1280, height=720, fps=30; double exposure=-1, gain=-1; int pupilBlockSize=31; double pupilC=10; double roiScale=1.6; std::string outputMode="jpeg"; std::string modelPath="models/face_detection_yunet_2023mar.onnx"; };` and `Config load(const std::string& path);` (missing file → all defaults; unknown/malformed lines → warn to stderr, keep defaults).

- [ ] **Step 1: Write the failing test**

`software/test/test_config.cpp`:
```cpp
#include "doctest.h"
#include "pigaze/config.hpp"
#include <fstream>

TEST_CASE("missing file yields defaults") {
    auto c = pigaze::load("definitely_absent.ini");
    CHECK(c.width == 1280);
    CHECK(c.fps == 30);
}
TEST_CASE("known keys override defaults; junk ignored") {
    const char* p = "test_cfg_tmp.ini";
    std::ofstream(p) << "width=640\nfps=60\nnonsense line\nroiScale=2.0\n";
    auto c = pigaze::load(p);
    CHECK(c.width == 640);
    CHECK(c.fps == 60);
    CHECK(c.roiScale == doctest::Approx(2.0));
    CHECK(c.height == 720);  // untouched default
    std::remove(p);
}
```

- [ ] **Step 2: Run to verify it fails**
Run: `cmake --build software/build -j` — expect compile error (`config.hpp` missing).

- [ ] **Step 3: Implement `config.hpp` + `config.cpp`**

`software/include/pigaze/config.hpp`:
```cpp
#pragma once
#include <string>
namespace pigaze {
struct Config {
    int width = 1280, height = 720, fps = 30;
    double exposure = -1, gain = -1;   // -1 = auto/driver default
    int pupilBlockSize = 31;           // adaptiveThreshold block (odd)
    double pupilC = 10;                // adaptiveThreshold constant
    double roiScale = 1.6;             // eye ROI size vs inter-landmark
    std::string outputMode = "jpeg";   // "jpeg" | "none" | "mjpeg"
    std::string modelPath = "models/face_detection_yunet_2023mar.onnx";
};
Config load(const std::string& path);
}  // namespace pigaze
```

`software/src/config.cpp`:
```cpp
#include "pigaze/config.hpp"
#include <fstream>
#include <sstream>
#include <iostream>
namespace pigaze {
Config load(const std::string& path) {
    Config c; std::ifstream f(path);
    if (!f) return c;
    std::string line;
    while (std::getline(f, line)) {
        auto eq = line.find('=');
        if (line.empty() || line[0] == '#') continue;
        if (eq == std::string::npos) { std::cerr << "config: skip '" << line << "'\n"; continue; }
        std::string k = line.substr(0, eq), v = line.substr(eq + 1);
        try {
            if      (k == "width")         c.width = std::stoi(v);
            else if (k == "height")        c.height = std::stoi(v);
            else if (k == "fps")           c.fps = std::stoi(v);
            else if (k == "exposure")      c.exposure = std::stod(v);
            else if (k == "gain")          c.gain = std::stod(v);
            else if (k == "pupilBlockSize")c.pupilBlockSize = std::stoi(v);
            else if (k == "pupilC")        c.pupilC = std::stod(v);
            else if (k == "roiScale")      c.roiScale = std::stod(v);
            else if (k == "outputMode")    c.outputMode = v;
            else if (k == "modelPath")     c.modelPath = v;
            else std::cerr << "config: unknown key '" << k << "'\n";
        } catch (...) { std::cerr << "config: bad value for '" << k << "'\n"; }
    }
    return c;
}
}  // namespace pigaze
```
Update CMake: remove `src/placeholder.cpp`, delete that file, add `src/config.cpp` to `pigaze_core` and `test/test_config.cpp` to `pigaze_tests`. Write `config.example.ini` with the default keys commented.

- [ ] **Step 4: Build + run — expect PASS**
Run: `cmake -S software -B software/build && cmake --build software/build -j && ctest --test-dir software/build --output-on-failure`

- [ ] **Step 5: Commit**
```bash
git add software/ && git commit -m "feat(sw): config loader with defaults"
```

---

### Task 3: PupilDetector (IR dark-pupil) — the core CV

**Files:**
- Create: `software/include/pigaze/pupil_detector.hpp`, `software/src/pupil_detector.cpp`, `software/test/fixtures.hpp`, `software/test/test_pupil_detector.cpp`
- Modify: `software/CMakeLists.txt`

**Interfaces:**
- Consumes: `pigaze::Eye`, `pigaze::PupilResult`, `pigaze::Config`.
- Produces: `class PupilDetector { public: explicit PupilDetector(const Config&); PupilResult detect(const cv::Mat& gray, const Eye& eye) const; };` — `gray` is full-frame 8-bit; returns center/glint in **full-frame** coords; `valid=false` when no plausible pupil.

- [ ] **Step 1: Write shared fixtures + failing test**

`software/test/fixtures.hpp`:
```cpp
#pragma once
#include <opencv2/imgproc.hpp>
#include "pigaze/types.hpp"
// Gray 8-bit frame with a dark pupil disk (+optional bright glint) inside an eye ROI.
inline cv::Mat makeEyeFrame(cv::Rect roi, cv::Point2f pupil, int pupilR,
                            int bg=140, bool glint=false, cv::Point2f gpt={}) {
    cv::Mat img(200, 320, CV_8UC1, cv::Scalar(bg));
    cv::rectangle(img, roi, cv::Scalar(bg-20), cv::FILLED);           // eye socket, slightly darker
    cv::circle(img, pupil, pupilR, cv::Scalar(15), cv::FILLED);       // dark pupil
    if (glint) cv::circle(img, gpt, 2, cv::Scalar(255), cv::FILLED);  // IR glint
    return img;
}
```

`software/test/test_pupil_detector.cpp`:
```cpp
#include "doctest.h"
#include "pigaze/pupil_detector.hpp"
#include "fixtures.hpp"

TEST_CASE("finds a centered dark pupil within 1.5 px") {
    cv::Rect roi(120, 70, 80, 60);
    cv::Point2f pupil(160, 100);
    auto img = makeEyeFrame(roi, pupil, 10);
    pigaze::Config cfg;
    pigaze::PupilDetector det(cfg);
    auto r = det.detect(img, pigaze::Eye{roi, {160,100}, true});
    REQUIRE(r.valid);
    CHECK(cv::norm(r.center - pupil) < 1.5);
}
TEST_CASE("no pupil -> invalid, no garbage") {
    cv::Rect roi(120, 70, 80, 60);
    cv::Mat flat(200, 320, CV_8UC1, cv::Scalar(140));
    pigaze::PupilDetector det(pigaze::Config{});
    auto r = det.detect(flat, pigaze::Eye{roi, {160,100}, true});
    CHECK_FALSE(r.valid);
}
TEST_CASE("glint is the brightest spot in the ROI") {
    cv::Rect roi(120, 70, 80, 60);
    auto img = makeEyeFrame(roi, {160,100}, 10, 140, true, {168,96});
    auto r = pigaze::PupilDetector(pigaze::Config{}).detect(img, pigaze::Eye{roi,{160,100},true});
    REQUIRE(r.glint.has_value());
    CHECK(cv::norm(*r.glint - cv::Point2f(168,96)) < 2.0);
}
```

- [ ] **Step 2: Run to verify it fails** — expect compile error (no `pupil_detector.hpp`).

- [ ] **Step 3: Implement**

`software/include/pigaze/pupil_detector.hpp`:
```cpp
#pragma once
#include "pigaze/types.hpp"
#include "pigaze/config.hpp"
namespace pigaze {
class PupilDetector {
public:
    explicit PupilDetector(const Config& cfg) : cfg_(cfg) {}
    PupilResult detect(const cv::Mat& gray, const Eye& eye) const;
private:
    Config cfg_;
};
}  // namespace pigaze
```

`software/src/pupil_detector.cpp`:
```cpp
#include "pigaze/pupil_detector.hpp"
#include <opencv2/imgproc.hpp>
#include <vector>
namespace pigaze {
PupilResult PupilDetector::detect(const cv::Mat& gray, const Eye& eye) const {
    PupilResult out;
    cv::Rect roi = eye.roi & cv::Rect(0, 0, gray.cols, gray.rows);
    if (roi.area() <= 0) return out;
    cv::Mat sub = gray(roi), blur, bin;
    cv::GaussianBlur(sub, blur, cv::Size(5, 5), 0);
    int bs = cfg_.pupilBlockSize | 1;  // force odd
    cv::adaptiveThreshold(blur, bin, 255, cv::ADAPTIVE_THRESH_MEAN_C,
                          cv::THRESH_BINARY_INV, bs, cfg_.pupilC);  // dark -> white
    std::vector<std::vector<cv::Point>> cs;
    cv::findContours(bin, cs, cv::RETR_EXTERNAL, cv::CHAIN_APPROX_SIMPLE);
    double best = 0; int bi = -1;
    for (int i = 0; i < (int)cs.size(); ++i) {
        double a = cv::contourArea(cs[i]);
        if (a < 20 || cs[i].size() < 5) continue;
        double per = cv::arcLength(cs[i], true);
        double circ = per > 0 ? 4 * CV_PI * a / (per * per) : 0;  // 1.0 = perfect circle
        if (circ < 0.5) continue;
        double score = a * circ;
        if (score > best) { best = score; bi = i; }
    }
    if (bi >= 0) {
        cv::RotatedRect e = cv::fitEllipse(cs[bi]);
        out.center = e.center + cv::Point2f((float)roi.x, (float)roi.y);
        out.radius = (e.size.width + e.size.height) / 4.f;
        out.confidence = (float)std::min(1.0, best / (roi.area() * 0.2));
        out.valid = true;
    }
    double mn, mx; cv::Point mnL, mxL;
    cv::minMaxLoc(sub, &mn, &mx, &mnL, &mxL);
    if (mx > 220) out.glint = cv::Point2f(mxL.x + roi.x, mxL.y + roi.y);
    return out;
}
}  // namespace pigaze
```
Add `src/pupil_detector.cpp` to `pigaze_core`; add `test/test_pupil_detector.cpp` (and `-I test` for `fixtures.hpp`) to `pigaze_tests`.

- [ ] **Step 4: Build + run — expect PASS** (`ctest --test-dir software/build --output-on-failure`)

- [ ] **Step 5: Commit**
```bash
git add software/ && git commit -m "feat(sw): IR dark-pupil detector (ellipse fit + glint)"
```

---

### Task 4: Telemetry (log + annotate + JPEG dump)

**Files:**
- Create: `software/include/pigaze/telemetry.hpp`, `software/src/telemetry.cpp`, `software/test/test_telemetry.cpp`
- Modify: `software/CMakeLists.txt`

**Interfaces:**
- Consumes: `PupilResult`, `Eye`.
- Produces: `class Telemetry { public: static std::string logLine(int frame, const std::vector<PupilResult>&); static void annotate(cv::Mat& bgr, const std::vector<PupilResult>&); static bool writeJpeg(const std::string& path, const cv::Mat& img); };`

- [ ] **Step 1: Write the failing test**

`software/test/test_telemetry.cpp`:
```cpp
#include "doctest.h"
#include "pigaze/telemetry.hpp"

TEST_CASE("logLine reports coords and validity") {
    pigaze::PupilResult a; a.valid = true; a.center = {12.0f, 34.0f}; a.confidence = 0.9f;
    auto s = pigaze::Telemetry::logLine(7, {a});
    CHECK(s.find("frame=7") != std::string::npos);
    CHECK(s.find("12") != std::string::npos);
    CHECK(s.find("34") != std::string::npos);
}
TEST_CASE("annotate marks the pupil pixel") {
    cv::Mat img(100, 100, CV_8UC3, cv::Scalar(0,0,0));
    pigaze::PupilResult a; a.valid = true; a.center = {50,50}; a.radius = 6;
    pigaze::Telemetry::annotate(img, {a});
    CHECK(cv::countNonZero(img.reshape(1)) > 0);  // something was drawn
}
```

- [ ] **Step 2: Run to verify it fails.**

- [ ] **Step 3: Implement**

`software/include/pigaze/telemetry.hpp`:
```cpp
#pragma once
#include <string>
#include <vector>
#include "pigaze/types.hpp"
namespace pigaze {
class Telemetry {
public:
    static std::string logLine(int frame, const std::vector<PupilResult>& rs);
    static void annotate(cv::Mat& bgr, const std::vector<PupilResult>& rs);
    static bool writeJpeg(const std::string& path, const cv::Mat& img);
};
}  // namespace pigaze
```

`software/src/telemetry.cpp`:
```cpp
#include "pigaze/telemetry.hpp"
#include <opencv2/imgproc.hpp>
#include <opencv2/imgcodecs.hpp>
#include <sstream>
namespace pigaze {
std::string Telemetry::logLine(int frame, const std::vector<PupilResult>& rs) {
    std::ostringstream o; o << "frame=" << frame;
    for (size_t i = 0; i < rs.size(); ++i) {
        o << " eye" << i << "=";
        if (rs[i].valid) o << "(" << rs[i].center.x << "," << rs[i].center.y
                           << ",c" << rs[i].confidence << ")";
        else o << "invalid";
    }
    return o.str();
}
void Telemetry::annotate(cv::Mat& bgr, const std::vector<PupilResult>& rs) {
    for (const auto& r : rs) {
        if (!r.valid) continue;
        cv::circle(bgr, r.center, std::max(2, (int)r.radius), cv::Scalar(0,255,0), 1);
        cv::drawMarker(bgr, r.center, cv::Scalar(0,0,255), cv::MARKER_CROSS, 6, 1);
        if (r.glint) cv::circle(bgr, *r.glint, 2, cv::Scalar(255,0,0), 1);
    }
}
bool Telemetry::writeJpeg(const std::string& path, const cv::Mat& img) {
    return cv::imwrite(path, img);
}
}  // namespace pigaze
```
Add to CMake (`src/telemetry.cpp`, `test/test_telemetry.cpp`).

- [ ] **Step 4: Build + run — expect PASS.**
- [ ] **Step 5: Commit**
```bash
git add software/ && git commit -m "feat(sw): telemetry log/annotate/jpeg"
```

---

### Task 5: Golden verification harness (synthetic frames)

**Files:**
- Create: `software/test/test_golden.cpp`
- Modify: `software/CMakeLists.txt`

**Interfaces:**
- Consumes: `PupilDetector`, `makeEyeFrame` (fixtures), `Eye`.
- Produces: nothing (test-only). Establishes the tolerance gate the spec requires; real recorded frames are dropped into `test/data/` during Pi bring-up (Task 7) and appended here.

- [ ] **Step 1: Write the golden test (a sweep of known centers)**

`software/test/test_golden.cpp`:
```cpp
#include "doctest.h"
#include "pigaze/pupil_detector.hpp"
#include "fixtures.hpp"

TEST_CASE("golden: pupil center within 2 px across a grid of positions") {
    pigaze::PupilDetector det(pigaze::Config{});
    cv::Rect roi(110, 60, 100, 80);
    int hits = 0, total = 0;
    for (int dx = -20; dx <= 20; dx += 10)
        for (int dy = -15; dy <= 15; dy += 15) {
            cv::Point2f p(160 + dx, 100 + dy);
            auto img = makeEyeFrame(roi, p, 9, 140, true, {p.x+6, p.y-6});
            auto r = det.detect(img, pigaze::Eye{roi, {160,100}, true});
            ++total;
            if (r.valid && cv::norm(r.center - p) < 2.0) ++hits;
        }
    CHECK(hits == total);  // 15/15 must pass
}
```

- [ ] **Step 2: Build + run — expect PASS** (the detector from Task 3 must clear the whole grid).
If any position fails, fix the detector (Task 3), do not loosen the tolerance without cause.

- [ ] **Step 3: Commit**
```bash
git add software/ && git commit -m "test(sw): golden pupil-center tolerance gate"
```

---

### Task 6: FaceEyes (YuNet) — face box + eye ROIs

**Files:**
- Create: `software/include/pigaze/face_eyes.hpp`, `software/src/face_eyes.cpp`, `software/test/test_face_eyes.cpp`, `software/models/` (model), `software/test/data/face_sample.jpg` (a freely-licensed, front-facing face photo the user supplies or a CC0 image)
- Modify: `software/CMakeLists.txt`

**Interfaces:**
- Consumes: `Config`, `Eye`.
- Produces: `class FaceEyes { public: bool load(const std::string& modelPath, cv::Size input); std::vector<Eye> detect(const cv::Mat& gray, double roiScale) const; };` — returns up to 2 `Eye`s (left/right) with `roi` a square of side `roiScale × inter-eye-distance/…` centered on each YuNet eye landmark.

- [ ] **Step 1: Fetch the model**

Run: `curl -L -o software/models/face_detection_yunet_2023mar.onnx https://github.com/opencv/opencv_zoo/raw/main/models/face_detection_yunet/face_detection_yunet_2023mar.onnx`
Expected: ~230 KB ONNX file.

- [ ] **Step 2: Write the failing test** (needs `data/face_sample.jpg`; if absent, the test is skipped via `doctest` `WARN` + early return)

`software/test/test_face_eyes.cpp`:
```cpp
#include "doctest.h"
#include "pigaze/face_eyes.hpp"
#include <opencv2/imgcodecs.hpp>

TEST_CASE("YuNet finds a face and two eyes in a sample image") {
    cv::Mat gray = cv::imread("test/data/face_sample.jpg", cv::IMREAD_GRAYSCALE);
    if (gray.empty()) { WARN("no face_sample.jpg; skipping"); return; }
    pigaze::FaceEyes fe;
    REQUIRE(fe.load("models/face_detection_yunet_2023mar.onnx", gray.size()));
    auto eyes = fe.detect(gray, 1.6);
    CHECK(eyes.size() == 2);
    for (auto& e : eyes) CHECK(e.roi.area() > 0);
}
```

- [ ] **Step 3: Implement with `cv::FaceDetectorYN`**

`software/src/face_eyes.cpp` (key logic):
```cpp
#include "pigaze/face_eyes.hpp"
#include <opencv2/objdetect.hpp>
#include <opencv2/imgproc.hpp>
namespace pigaze {
struct FaceEyes::Impl { cv::Ptr<cv::FaceDetectorYN> det; cv::Size in; };
bool FaceEyes::load(const std::string& m, cv::Size input) {
    impl_ = std::make_shared<Impl>();
    impl_->in = input;
    impl_->det = cv::FaceDetectorYN::create(m, "", input, 0.7f, 0.3f, 5000);
    return impl_->det != nullptr;
}
std::vector<Eye> FaceEyes::detect(const cv::Mat& gray, double roiScale) const {
    std::vector<Eye> out;
    if (!impl_ || !impl_->det) return out;
    cv::Mat bgr; cv::cvtColor(gray, bgr, cv::COLOR_GRAY2BGR);
    cv::Mat faces; impl_->det->detect(bgr, faces);
    if (faces.rows < 1) return out;
    // Row 0 = highest score. Cols 4..13 = 5 landmarks (x,y): [0]=right eye [1]=left eye.
    const float* f = faces.ptr<float>(0);
    cv::Point2f re(f[4], f[5]), le(f[6], f[7]);
    float d = (float)cv::norm(re - le);
    int s = std::max(16, (int)(roiScale * d * 0.5f));
    auto mk = [&](cv::Point2f c, bool left) {
        cv::Rect r(int(c.x - s/2), int(c.y - s/2), s, s);
        out.push_back(Eye{ r & cv::Rect(0,0,gray.cols,gray.rows), c, left });
    };
    mk(le, true); mk(re, false);
    return out;
}
}  // namespace pigaze
```
`face_eyes.hpp` declares the class with a `std::shared_ptr<Impl> impl_;` (pimpl to keep OpenCV objdetect out of the header). Add sources/tests to CMake. Copy `models/` and `test/data/` next to the test binary or run tests from `software/` (working dir matters for the relative paths).

- [ ] **Step 4: Build + run — expect PASS (or SKIP if no sample image).**
- [ ] **Step 5: Commit**
```bash
git add software/ && git commit -m "feat(sw): YuNet face/eye localization"
```

---

### Task 7: Camera (libcamera via GStreamer) — Pi bring-up

**Files:**
- Create: `software/include/pigaze/camera.hpp`, `software/src/camera.cpp`, `software/test/test_camera.cpp`
- Modify: `software/CMakeLists.txt`

**Interfaces:**
- Consumes: `Config`.
- Produces: `class Camera { public: bool open(const Config&); bool next(cv::Mat& gray); std::string pipeline(const Config&) const; };` — `pipeline()` builds the GStreamer string (pure, unit-testable); `open()`/`next()` need real hardware.

- [ ] **Step 1: Pre-flight on the Pi (manual)**
Run on the Pi: `rpicam-hello --timeout 2000` — expect the camera preview/log (proves libcamera sees Camera Module 3). If this fails, stop and fix the camera before continuing.

- [ ] **Step 2: Write the failing (pure) test for the pipeline string**

`software/test/test_camera.cpp`:
```cpp
#include "doctest.h"
#include "pigaze/camera.hpp"
TEST_CASE("pipeline embeds libcamerasrc and the requested size/fps") {
    pigaze::Config c; c.width = 1280; c.height = 720; c.fps = 30;
    auto p = pigaze::Camera().pipeline(c);
    CHECK(p.find("libcamerasrc") != std::string::npos);
    CHECK(p.find("1280") != std::string::npos);
    CHECK(p.find("appsink") != std::string::npos);
}
```

- [ ] **Step 3: Implement**

`software/src/camera.cpp` (key parts):
```cpp
#include "pigaze/camera.hpp"
#include <opencv2/videoio.hpp>
#include <opencv2/imgproc.hpp>
#include <sstream>
namespace pigaze {
std::string Camera::pipeline(const Config& c) const {
    std::ostringstream o;
    o << "libcamerasrc ! video/x-raw,width=" << c.width
      << ",height=" << c.height << ",framerate=" << c.fps << "/1"
      << " ! videoconvert ! video/x-raw,format=BGR ! appsink drop=true max-buffers=2";
    return o.str();
}
bool Camera::open(const Config& c) {
    cap_.open(pipeline(c), cv::CAP_GSTREAMER);
    return cap_.isOpened();
}
bool Camera::next(cv::Mat& gray) {
    cv::Mat bgr;
    if (!cap_.read(bgr) || bgr.empty()) return false;
    cv::cvtColor(bgr, gray, cv::COLOR_BGR2GRAY);
    return true;
}
}  // namespace pigaze
```
`camera.hpp` holds a `cv::VideoCapture cap_;`. Add a **guarded** integration test (runs only if `PIGAZE_CAMERA=1`) that opens and grabs one non-empty frame. Add to CMake.

- [ ] **Step 4: Build + run** — pure pipeline test PASS on any box; on the Pi with camera: `PIGAZE_CAMERA=1 ctest --test-dir software/build -R camera --output-on-failure`.
- [ ] **Step 5: Commit**
```bash
git add software/ && git commit -m "feat(sw): libcamera/GStreamer capture"
```

---

### Task 8: App loop (`main`) + example config

**Files:**
- Create: `software/src/main.cpp`
- Modify: `software/CMakeLists.txt` (add `pigaze` executable = `main.cpp` + `pigaze_core`)

**Interfaces:**
- Consumes: `Config load()`, `Camera`, `FaceEyes`, `PupilDetector`, `Telemetry`.
- Produces: the `pigaze` binary.

- [ ] **Step 1: Implement the loop**

`software/src/main.cpp`:
```cpp
#include "pigaze/config.hpp"
#include "pigaze/camera.hpp"
#include "pigaze/face_eyes.hpp"
#include "pigaze/pupil_detector.hpp"
#include "pigaze/telemetry.hpp"
#include <opencv2/imgproc.hpp>
#include <csignal>
#include <iostream>
#include <chrono>
static volatile std::sig_atomic_t g_stop = 0;
int main(int argc, char** argv) {
    std::signal(SIGINT, [](int){ g_stop = 1; });
    auto cfg = pigaze::load(argc > 1 ? argv[1] : "config.ini");
    pigaze::Camera cam;
    if (!cam.open(cfg)) { std::cerr << "camera open failed\n"; return 1; }
    pigaze::FaceEyes fe;
    if (!fe.load(cfg.modelPath, {cfg.width, cfg.height}))
        { std::cerr << "model load failed: " << cfg.modelPath << "\n"; return 2; }
    pigaze::PupilDetector det(cfg);
    cv::Mat gray; int frame = 0; auto t0 = std::chrono::steady_clock::now();
    while (!g_stop) {
        if (!cam.next(gray)) continue;
        auto eyes = fe.detect(gray, cfg.roiScale);
        std::vector<pigaze::PupilResult> rs;
        for (auto& e : eyes) rs.push_back(det.detect(gray, e));
        std::cout << pigaze::Telemetry::logLine(frame, rs) << "\n";
        if (cfg.outputMode == "jpeg" && frame % 15 == 0) {
            cv::Mat bgr; cv::cvtColor(gray, bgr, cv::COLOR_GRAY2BGR);
            pigaze::Telemetry::annotate(bgr, rs);
            pigaze::Telemetry::writeJpeg("last_frame.jpg", bgr);
        }
        ++frame;
    }
    auto dt = std::chrono::duration<double>(std::chrono::steady_clock::now()-t0).count();
    std::cerr << "avg fps=" << (frame/dt) << "\n";
    return 0;
}
```
Add the `pigaze` executable to CMake.

- [ ] **Step 2: Build — expect success** (`cmake --build software/build -j`).
- [ ] **Step 3: Run on the Pi (manual smoke)**
Run: `cd software && ./build/pigaze config.example.ini` — sit ~60 cm away; `scp` or view `last_frame.jpg` and confirm the green pupil markers land on your pupils. Confirm `avg fps ≥ 15`.
- [ ] **Step 4: Commit**
```bash
git add software/ && git commit -m "feat(sw): app loop wiring camera->faceeyes->pupil->telemetry"
```

---

## Self-Review

**Spec coverage:** capture (T7), face+eye localization YuNet (T6), pupil center per eye (T3), glint (T3), confidence (T3), headless verify: annotated JPEG (T4) + golden gate (T5) + FPS (T8), config (T2), error handling: camera fail (T7/T8), no face (T6 returns empty → T8 emits invalid), low-confidence invalid (T3). MJPEG output mode is declared in Config but implemented as JPEG dump in v1; MJPEG is explicitly out of the v1 build (spec lists it "optional") — noted, not a gap.

**Placeholder scan:** no TBD/TODO; every code step has real code; tests carry real assertions.

**Type consistency:** `PupilResult`/`Eye` (T1) used unchanged in T3/T4/T6/T8; `Config` fields (T2) referenced by exact name in T3 (`pupilBlockSize`,`pupilC`), T6 (`roiScale`,`modelPath`), T7 (`width`/`height`/`fps`), T8. `PupilDetector::detect(gray, eye)`, `FaceEyes::load/detect`, `Camera::open/next/pipeline`, `Telemetry::logLine/annotate/writeJpeg` names match across tasks.

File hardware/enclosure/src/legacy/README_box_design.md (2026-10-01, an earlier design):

# Pi-Gaze — корпус айтрекера. Готов к печати.

Айтрекер на Raspberry Pi 5 + Camera Module 3 NoIR + ИК-подсветка.
Крепится на верхнюю кромку монитора; блок Pi висит за монитором и работает противовесом.

## Структура исходников

    src/params.scad   все размеры (единственный источник правды)
    src/lib.scad      примитивы (скругления, втулки, магниты, проёмы)
    src/box.scad      блок Raspberry Pi + крышка
    src/bar.scad      оптический бар (камера + ИК) + крышка
    src/clamp.scad    тиски + прокладка + пятка барашка
    src/pigaze.scad   ГЛАВНЫЙ файл (сборка и выбор детали)

    ./build.sh        экспорт всех STL + проверка манифольдности
    ./render.sh       превью всех деталей в out/
    src/check.scad    КОНТР-МОДЕЛЬ: ghost-габариты компонентов в сборочных позах
    ./check.sh        прогон всех пересечений (пусто = коллизии нет)

## Откуда взяты размеры (проверяемо)

Позиции и габариты разъёмов **измерены с официального чертежа Raspberry Pi 5**
пиксельно, а не взяты на глаз. Масштаб установлен по контуру платы: 1446 x 952 px
при 85 x 56 мм даёт **17.01 px/мм** (сходится с тем, что чертёж 1:1 на A4).

Контроль метода: измеренные центры разъёмов совпали с размерными надписями
самого чертежа **до сотых миллиметра** — значит измерение корректно.

| Разъём | Центр измерен | Центр по чертежу | Тело измерено |
|---|---|---|---|
| USB-C | 11.20 | 11.2 | **8.76** |
| micro-HDMI 0 | 25.72 | 25.8 | **7.03** |
| micro-HDMI 1 | 39.20 | 39.2 | **7.03** |
| USB-A стек | 29.00 | 29.1 | **13.05** |
| USB-A стек | 46.98 | 47.0 | **13.05** |
| RJ45 | 10.18 | 10.2 | **15.99** |

Высоты: USB-C и micro-HDMI — из размерных надписей бокового вида (3.2 / 3.4 / 4.4,
берём худший случай 4.4). USB-стек 15.0 и Ethernet 14.0 — замер штангенциркулем.

**Проёмы = тело + ~0.7 мм суммарного зазора (0.35 на сторону)** — снуг для FDM,
где типовой допуск ±0.2 мм. **Тела разъёмов и их центры перепроверены прямым замером
на реальной 3D-модели** (`RASPBERRY_PI_5_WITH_ACTIVE_COOLER.stl`): плата в модели
центрирована в нуле (нижняя медь ровно 85×56), отображение в корпус — worldX = B,
worldZ = 48 − A. **Центры всех шести разъёмов совпали с чертёжными до 0.1 мм.**

| Разъём | Тело (STL) | Проём | Центр (world), STL = чертёж |
|---|---|---|---|
| USB-C | 8.94 × 3.16 | **9.6 × 4.6** | Z 79.3 = 79.3 |
| micro-HDMI ×2 | 6.50 × 2.88 | **7.3 × 4.4** | Z 64.7 / 51.3 |
| USB-A стек ×2 | 13.25 × 15.80 | **14.0 × 16.5** | X −1.1 / −19.0 |
| RJ45 | 15.90 × 13.68 | **16.6 × 14.4** | X +17.8 |

Замер вскрыл один реальный дефект: прежняя высота проёма USB-стека (15.7) была **равна
телу разъёма (15.8) — нулевой зазор**; поднято до 16.5. Ширины USB-C/USB чуть добраны.

Прочее: плата 85x56 и крепёж 58x49 — тот же чертёж; камера 25x24x11.5 — official
product brief Camera Module 3.

**microSD наружу не выведен намеренно.** По чертежу карта стоит вплотную к USB-C:
между проёмами оставалась перемычка 1.1 мм — тонко и неопрятно. Крышка магнитная и
снимается за секунду, карта меняется через неё.

## Раскладка разъёмов

Плата стоит ребром CAM/DISP **вверх**, **вентилятором к крышке** (интейк турбинки
смотрит на решётку крышки, а не в глухую стенку). Раскладка сверена с реальной платой —
если смотреть на вентилятор (со стороны крышки):

| Грань | Что выходит |
|---|---|
| **Верх** | шлейф камеры (CSI), толкатель кнопки питания, выброс тепла (SD — через крышку) |
| **Низ** | Ethernet, USB-стек, USB-стек |
| **Лево** | USB-C (питание), micro-HDMI ×2 |
| **Право** | GPIO внутри, наружу — USB-штекер CH9329 |

Поля слева и справа **равные** — плата стоит по центру X, поэтому кулер и решётка
крышки тоже по центру. Отсек CH9329 вынесен в верхнее поле, где нет жёстких штекеров.

Внутренняя раскладка **отзеркалена по X** под установку платы вентилятором к крышке —
иначе, чтобы разъёмы совпали, плату пришлось бы класть вентилятором вниз (интейк в стенку).

Бокс крепится к тискам **задней стенкой** (2 болта M3 в термовтулки). Точка крепления —
на **спуре**, отходящем вниз от задней губки, поэтому блок Pi висит «хвостом» **ниже
барашка** и не перекрывает его (это ловил контр-модельный тест `asm_box_clamp`).
Силуэт чистый; сверху — шлейф, толкатель кнопки и выброс тепла.

## Печать

| Деталь | Материал | На стол | Пауза для магнитов |
|---|---|---|---|
| `box` | PETG / ASA | задней стенкой вниз | **31.2 мм** |
| `box_lid` | PETG / ASA | наружной гранью вниз | **0.8 мм** |
| `bar` | **чёрный** PETG | оптикой вниз (грань плоская) | **15.6 мм** |
| `bar_lid` | **чёрный** PETG | наружной гранью вниз | **0.8 мм** |
| `clamp` | PETG / ASA | перемычкой вниз | — |
| `pad` | **TPU** | плашмя | — |
| `foot` | **TPU** | плашмя | — |
| `knob` | PETG/ASA | плашмя | — |
| `plunger` | PETG/ASA | шляпкой вниз (без поддержки) | — |

* Бар — обязательно **чёрный** пластик: внутренние стенки не должны отражать ИК.
* Тиски — **не PLA**: держат постоянную нагрузку, PLA течёт и размягчается от 60 °C.
* Пауза (`M600`) — кладёшь по 4 магнита в открытые карманы, продолжаешь печать,
  слои их замуровывают. Снаружи магнитов не видно.

## Закупка

**Магниты:** неодим N42, диск **5 × 2 мм** — **16 шт** (по 4 на короб, крышку короба,
бар, крышку бара). ПО УГЛАМ. Полярность: в детали все одной стороной, в парной крышке —
противоположной. Пометь маркером до укладки, иначе крышка будет отталкиваться.

**Крепёж: втулки — ТОЛЬКО в плате, всё прочее — гайки в карманах, единый M3.**

| Позиция | Точный размер | Кол-во | Куда |
|---|---|---|---|
| Термовтулка heat-set **M2.5** (латунь) | под отв. Ø3.5, L≈5 | **2** | крепление платы |
| Винт **M2.5×8** цилиндр. головка | M2.5×8 | 2 | плата → втулки |
| Болт **M3×40** шестигр. головка DIN933 | M3×40 | 1 | барашек (в печатную ручку) |
| Винт **M3×30** | M3×30 | 1 | ось шарнира + фиксация угла |
| Винт **M3×10** (или ×12) | M3×10 | 2 | док (блок → тиски) |
| Гайка **M3** обычная DIN934/ISO4032 | M3 | **4** | шарнир 1 + док 2 + барашек 1 |

Печатаются (НЕ покупать): ручка-маховик `knob` (PETG), **толкатель кнопки `plunger` (PETG)**, пятка `foot` (TPU), прокладка `pad` (TPU).

**Электроника:** Raspberry Pi 5 8GB · Active Cooler · Camera Module 3 **NoIR** ·
кабель камеры для Pi 5 (**22→15 pin**, обязательно) · 2× Vishay TSHA5203 (ИК 875 нм) ·
2× резистор 180 Ω · ключевой транзистор (диоды питать от 5 В, не от GPIO!) ·
модуль CH9329 · USB-удлинитель.

## Ключевые инженерные решения

* **Плата ПРИКРУЧЕНА** 2 винтами M2.5 в термовтулки — в СВОБОДНУЮ диагональ монтажных
  отверстий Pi (Active Cooler занимает другую диагональ пружинными пинами, чертёж кулера
  63.5×42.5, пины по углам одной диагонали). Плюс лежит на 4 постах и 2 опорах в зазорах
  между разъёмами (не задевают штекеры, тест `botsup`). Диагональ винтов — `SCREW_DIAG`
  в `box.scad`, помечена VERIFY.
* **Магниты по углам.** 4 локальных прилива в углах, а не сплошные планки — центр
  горловины свободен, паяльник достаёт до бобышек (планки раньше мешали впайке).
* **Кулер — воздушный тракт, а не деталь.** Габарит Active Cooler (офиц. datasheet)
  63.5×42.5×**13.7 мм**; заложено 15 мм, над турбинкой к крышке остаётся 9.5 мм (нужно ≥8):
  приток через решётку крышки, выброс через верхнюю грань. Проверено пересечением
  реального габарита кулера с корпусом и крышкой (`cooler_box`, `cooler_lid`).
* **Светозащита бара.** Камера и каждый ИК-диод в своих отсеках за перегородками.
  Диод сидит в глухом колодце и светит через малую апертуру — прямой видимости
  «диод → объектив» внутри корпуса нет. Провода идут через отверстия в перегородках.
* **Крепёж — гайки в карманах (M3), кроме платы.** Гайка входит в печатный шестигранный
  карман, винт затягивается в неё — прочно, без паяльника (паяльник только для 2 втулок платы).
* **Барашек не портит монитор.** Винт M3 крутится за печатную ручку-маховик, упирается в
  отдельную пятку с шаровым гнездом; к монитору прижимается плоская невращающаяся площадка.
  Прилив гнезда **врастает в площадку** (перекрытие 4 мм) — раньше он стартовал с зазором и
  «висел» отдельной шайбой; теперь пятка — цельный кусок (проверено: 1 связная оболочка).
* **Шарнир фиксируется положительно.** Гайка M3 в щеке вилки: затянул винт — угол держится
  жёстко (смена угла обнуляет калибровку). Ось поднята над мостом — вилка не задевает мост
  при наклоне (`asm_bar_clamp`).
* **Крышка бара НАКРЫВАЕТ камеру.** Крышка повторяет профиль бара (крылья + центральный
  прилив 32 мм), иначе отсек камеры оставался открыт сверху. Тест `lid_covers` доказывает
  полное перекрытие, `barlid_bar` — что крышка садится без коллизии со столбиками магнитов.
* **Печать без поддержки.** Выступающая бленда объектива убрана — она сидела по центру
  передней грани и заставляла бар печататься на кольце; теперь грань плоская, печать
  «оптикой вниз» чистая. Светозащиту диод↔объектив держит внутренний баффл (не бленда).
  Толкатель кнопки печатается шляпкой вниз (нет нависаний).
* **Шлейф камеры защищён.** Путь: камера (в баре) → выход у ОСИ ШАРНИРА (петля на наклон,
  шлейф не тянется) → канал на НИЖНЕЙ грани перемычки тисков (шлейф зажат между тисками и
  верхом монитора — не болтается, не цепляется) → вниз к боксу → широкий проём в ВЕРХНЕЙ
  грани короба над разъёмом CAM/DISP. Открытые участки короткие и за монитором.
* **Кнопка питания Pi 5 — сверху, через ТОЛКАТЕЛЬ.** Кромка платы (SD + кнопка) утоплена в
  верхнее поле (там CH9329 и защищённый вывод шлейфа), поэтому кнопку жмём печатным толкателем
  (`plunger`) в тубусе через верхнюю грань — без разборки. SD-карта на нижней стороне у этой же
  кромки — меняется снятием магнитной крышки. Позиция толкателя `PWR_TX` помечена VERIFY.
* **Отсек CH9329 — открытая колыбель.** Модуль 34 мм кладётся спереди при снятой крышке
  (закрытый отсек с окном 22 мм его бы не впустил); USB-торец смотрит в проём правой
  стенки, тело 15×9 не проходит через проём 13×7 — модуль зафиксирован.

## Контр-модель: как доказано, что корпус НЕ плохой

Мало сказать «манифольдно». Манифольдность не видит ни коллизий сборки, ни неверных
размеров. Поэтому рядом стоит **контр-модель** (`src/check.scad` + `./check.sh`): она
ставит ghost-габариты реальных компонентов в их **сборочные позы** и пересекает с
пластиком. **Любое непустое пересечение = деталь плохая.** Габариты — с авторитетных
источников (офиц. чертёж Pi 5, datasheet Active Cooler).

**20 проверок**, все PASS (пусто): кулер↔корпус/крышка, плата↔стенки, 6 разъёмов↔проёмы,
опоры↔штекеры, CH9329↔плата/опоры, камера↔бар, окно объектива, крышка↔камера
(`lid_covers`), крышка↔бар (`barlid_bar`), **толкатель↔направляющая** (`plunger_fit`),
**диапазон шарнира −48°** (`hinge_45`), и две СБОРОЧНЫЕ — бар↔тиски, бокс↔тиски. Плюс
арифметический лист зазоров (втулки, гайки-карманы, толкатель, барашек, шарнир) — чисто.

Контр-модель отработала: она **нашла 4 реальных дефекта**, каждый исправлен —

| # | Что нашла контр-модель | Исправление |
|---|---|---|
| 1 | Нижние полки платы налезали на RJ45 и USB (плата не садится) | Опоры перенесены в зазоры между разъёмами |
| 2 | В отсек CH9329 не влезал модуль (34 мм через окно 22 мм) | Отсек переделан в открытую колыбель |
| 3 | Вилка шарнира на 1 мм врезалась в мост тисков (клинит наклон) | Ось поднята — вилка проходит с зазором 2 мм |
| 4 | Барашек M5 упирался в заднюю стенку висящего блока | Док вынесен на спур — блок висит ниже барашка |

Прогнать самому: `./check.sh` (пусто по всем = коллизий нет), затем `./build.sh`.

## Сверка с РЕАЛЬНОЙ 3D-моделью Pi 5 + Active Cooler

Корпус наложен на настоящую модель платы с кулером (`ref/pi5_active_cooler.stl`,
120k треугольников). Подтверждено ПО ФАКТУ, а не по чертежу:
- **Габарит платы**: ребро 56.00 мм — точно; ребро ~85 мм; плата по центру X — как в корпусе.
- **Раскладка/зеркальность БЕЗ ошибки**: реальная плата ложится в корпус ПОВОРОТОМ (не
  отражением) — разъёмы попадают в свои проёмы (Eth/USB низ, HDMI/USB-C стенка +X, GPIO −X,
  CSI/SD верх). Наложение показало штекеры точно в прорезях.
- **Высота кулера = 13.70 мм** (замер по модели) — сходится с datasheet; над ним к крышке
  остаётся ~9 мм (нужно ≥8).
- **Монтажные отверстия**: в этой модели снизу все 4 свободны (пины кулера не выступают под
  платой) — винты платы M2.5 встают без конфликта; головки винтов вне габарита кулера.
- **SD снизу у верхней кромки**, **кнопка питания у угла USB-C/верх** — совпадает с выводом
  под толкатель и заменой SD через крышку.
- **Центры проёмов перенесены с модели** (worldX = B, worldZ = 48 − A): RJ45 X +17.8,
  USB X −1.1/−19.0, USB-C Z 79.3, HDMI Z 64.7/51.3 — всё **совпало с чертёжным до 0.1 мм**,
  так что зеркальность подтверждена численно, а не только на глаз. Размеры проёмов подогнаны
  под замеренные тела (см. таблицу выше); вскрыт нулевой зазор по высоте USB-стека — исправлен.
Булев тест-пересечение CGAL не прошёл (реальный STL не watertight — обычное дело для
CAD-экспортов сборок), поэтому сверка сделана наложением (`_overlay2.scad`) + замерами по вершинам.

Ещё исправлено: **(5)** заглушённое на 0.2 мм отверстие дока → сквозное; **(6) зеркальность**
раскладки по X (плата вентилятором к крышке); **(7)** крышка бара не накрывала камеру
(была 18 мм, прилив 32) → крышка по профилю бара; **(8)** бортик крышки бил в столбики
магнитов бара (`barlid_bar`, 944 грани) → вырезы в бортике.

## Что проверить на реальном железе

1. **Зеркальность — ПОДТВЕРЖДЕНА реальной моделью**: плата ложится поворотом, разъёмы в
   проёмах. Дополнительной проверки не требует.
2. **microSD** — грань подтверждена (верх), но точная координата X помечена
   VERIFY: параметр `SD_X` в `box.scad`, сейчас +21 мм от центра (после зеркалки).
3. **CH9329** — отсек под 34×15×9, сверь свой модуль.
4. **Active Cooler** — габарит 63.5×42.5×13.7 (офиц. datasheet); заложено 15 мм с запасом.
   Иной кулер — правь `COOLER_H` в `params.scad`.
5. **Кнопка питания (толкатель)** — `PWR_TX` в `box.scad` (сейчас X=24). Приложи к плате, чтобы
   тубус толкателя встал точно над кнопкой у верхней кромки. Печатаешь деталь `plunger`.
6. **Шлейф CAM/DISP** — проём в верхней грани широкий (24 мм); если нужно — сдвинь центр под
   свой разъём камеры (строка прорези в `box.scad`).

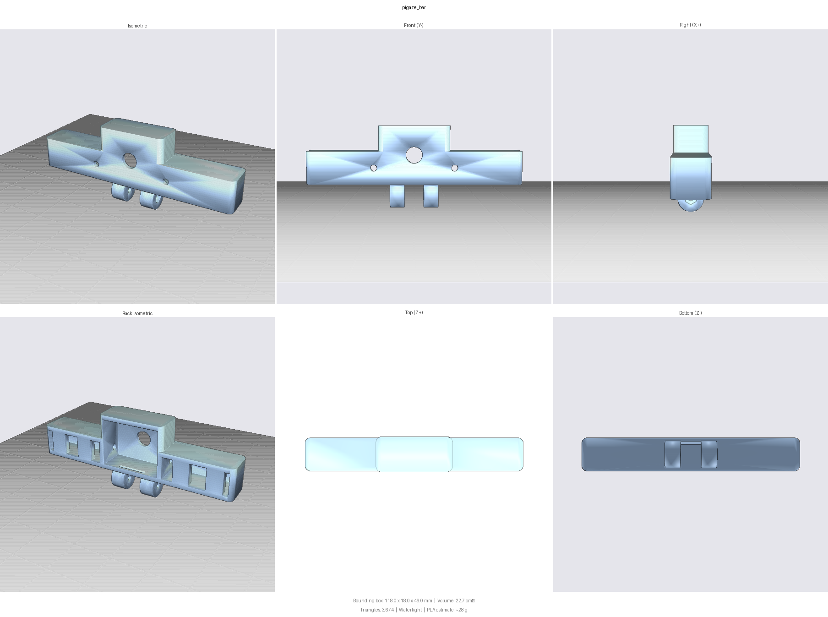
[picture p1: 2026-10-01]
hardware/renders/pigaze_bar_preview.png

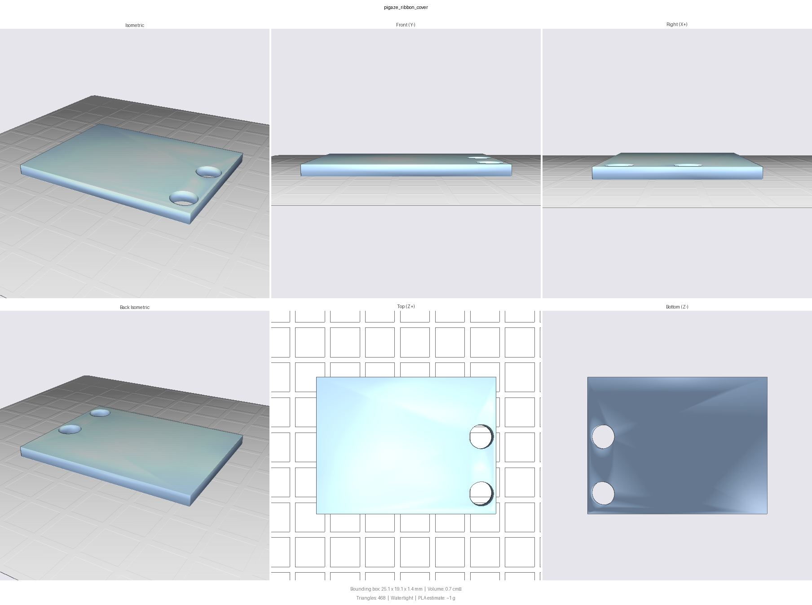
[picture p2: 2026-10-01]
hardware/renders/pigaze_ribbon_cover_preview.png

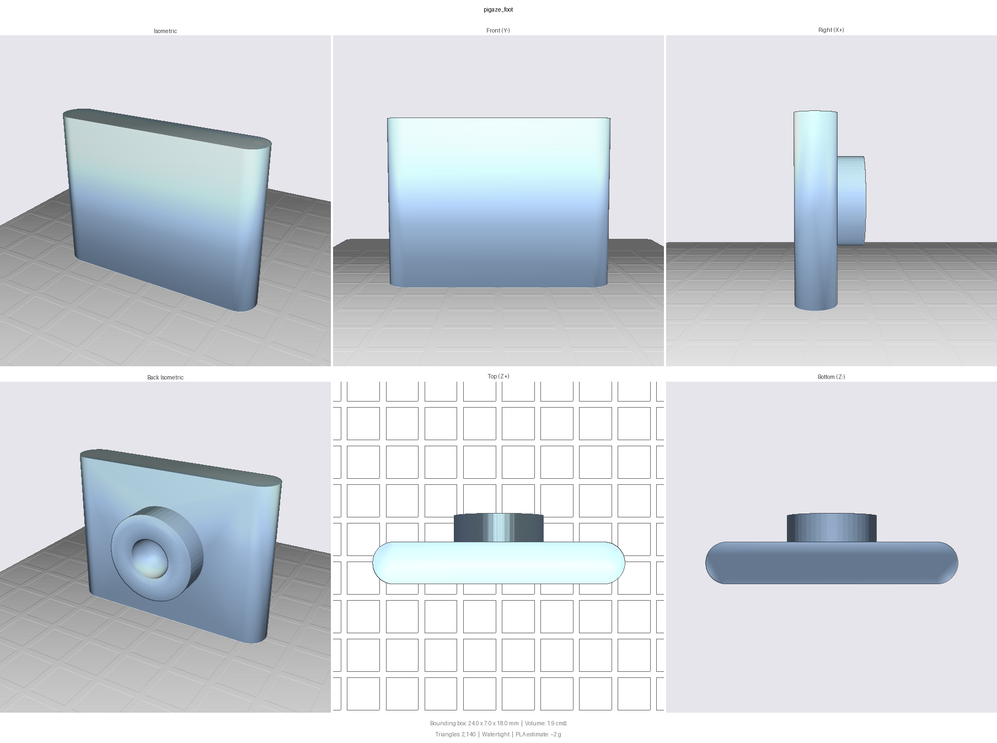
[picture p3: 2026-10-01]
hardware/renders/pigaze_foot_preview.png

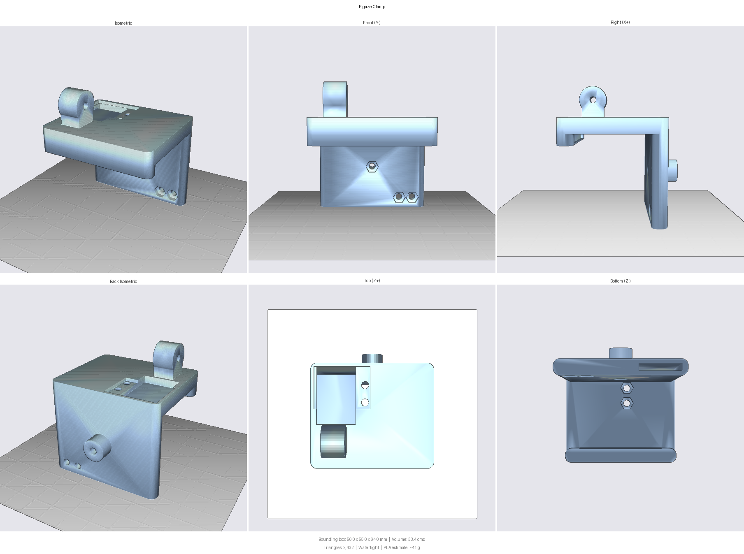
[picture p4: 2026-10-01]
hardware/renders/pigaze_clamp_preview.png

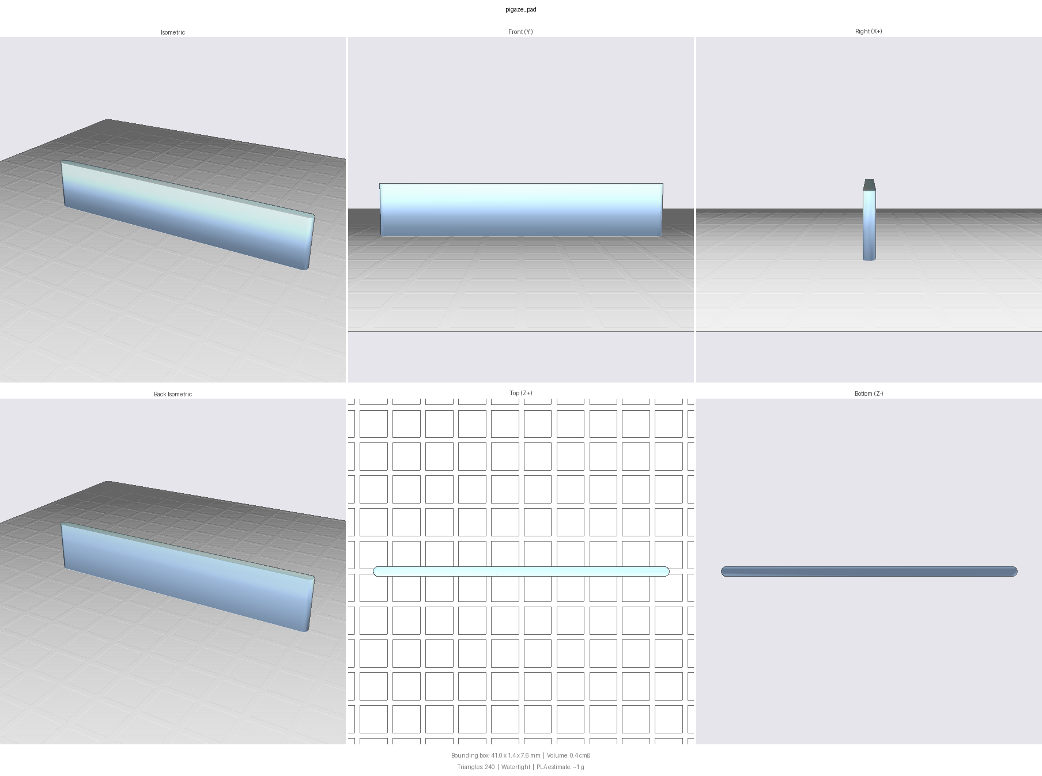
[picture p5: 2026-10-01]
hardware/renders/pigaze_pad_preview.png

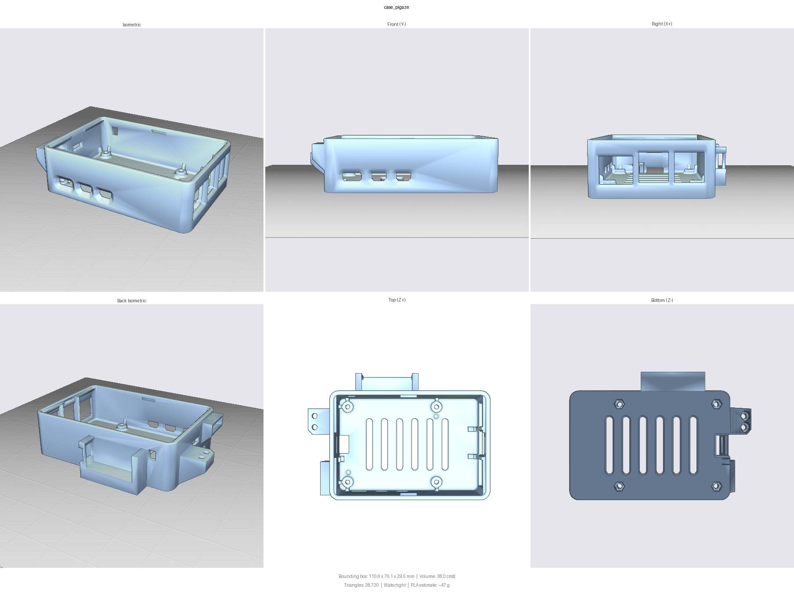
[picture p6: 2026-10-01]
hardware/renders/case_pigaze_preview.png

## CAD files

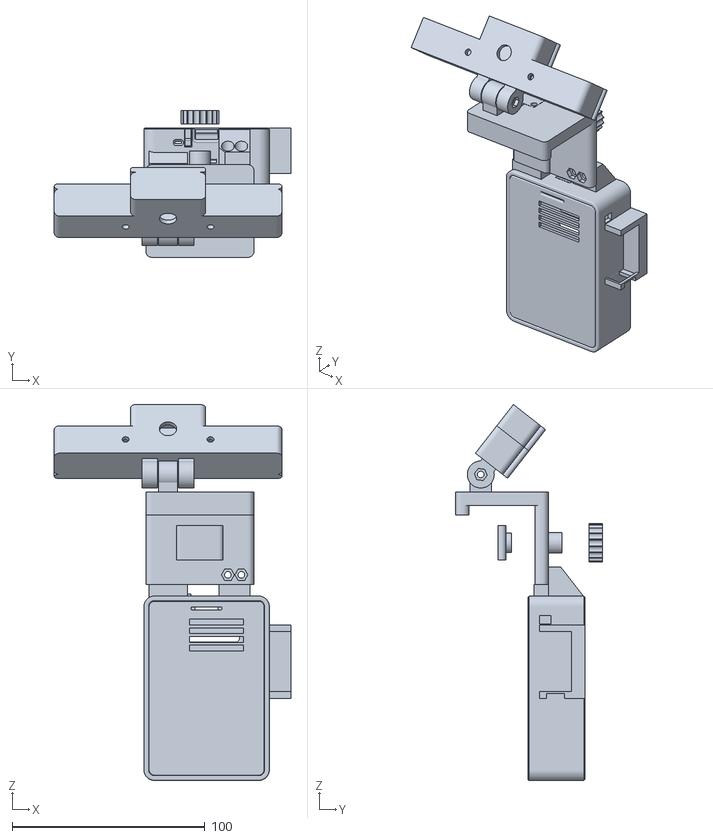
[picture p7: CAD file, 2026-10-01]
hardware/renders/assembly.stl
122.6 x 76.0 x 194.9

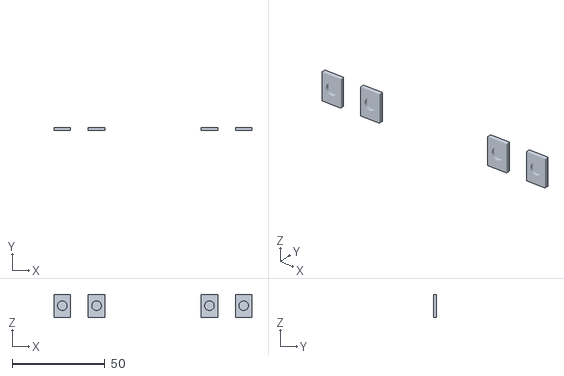
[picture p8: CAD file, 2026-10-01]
hardware/enclosure/out/chk/barlid_bar.stl
107.0 x 1.80 x 12.7

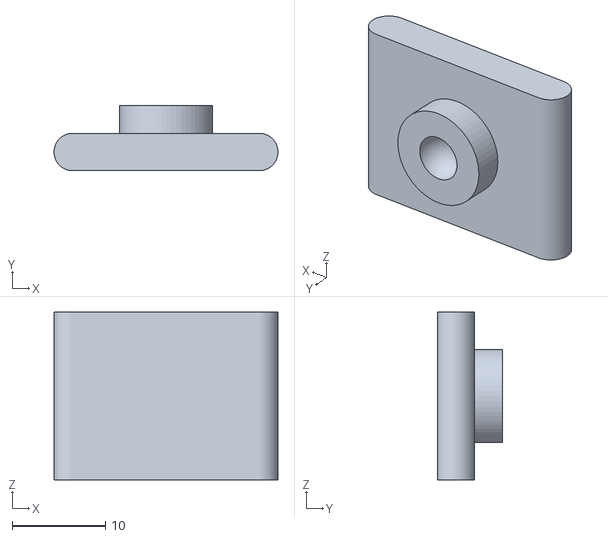
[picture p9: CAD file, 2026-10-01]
hardware/enclosure/out/pose/pose_foot.stl
24.0 x 7.00 x 18.0

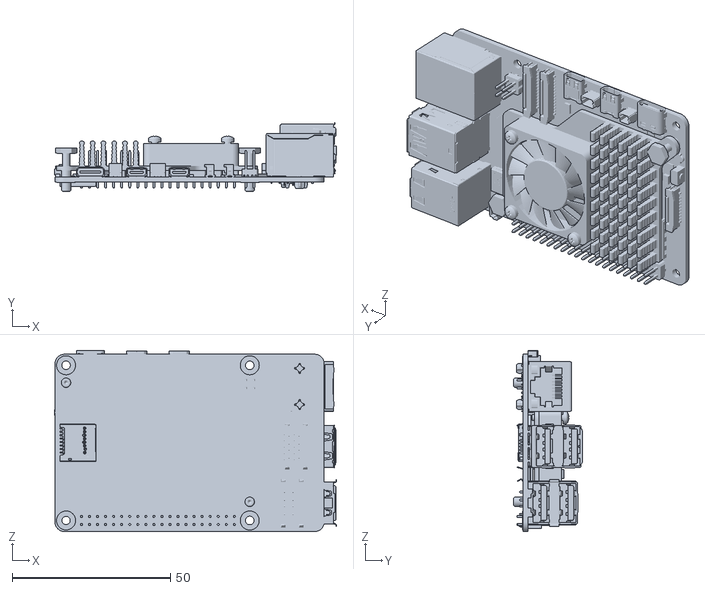
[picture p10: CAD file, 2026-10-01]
hardware/enclosure/ref/pi5_active_cooler.stl
89.0 x 21.6 x 57.2

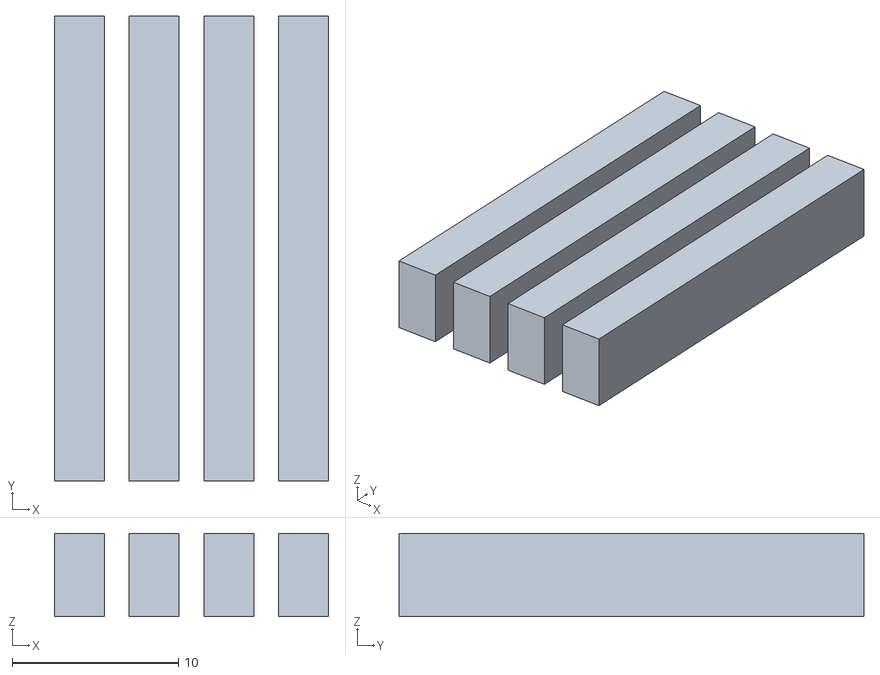
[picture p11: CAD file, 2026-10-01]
hardware/mount/_tmp/cover_cut.stl
16.5 x 28.0 x 5.00

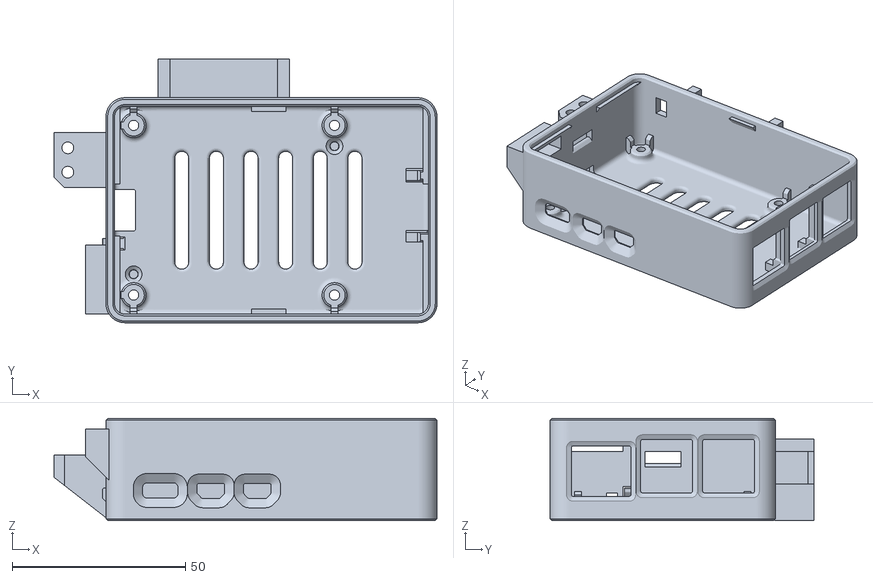
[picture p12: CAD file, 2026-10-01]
hardware/mount/case_pigaze.stl
110.6 x 76.1 x 29.5

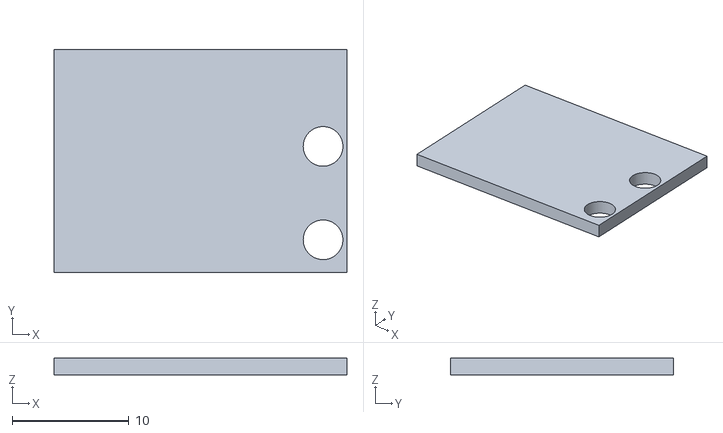
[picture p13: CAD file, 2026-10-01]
hardware/enclosure/out/pose/pose_ribbon_cover.stl
25.1 x 19.1 x 1.45

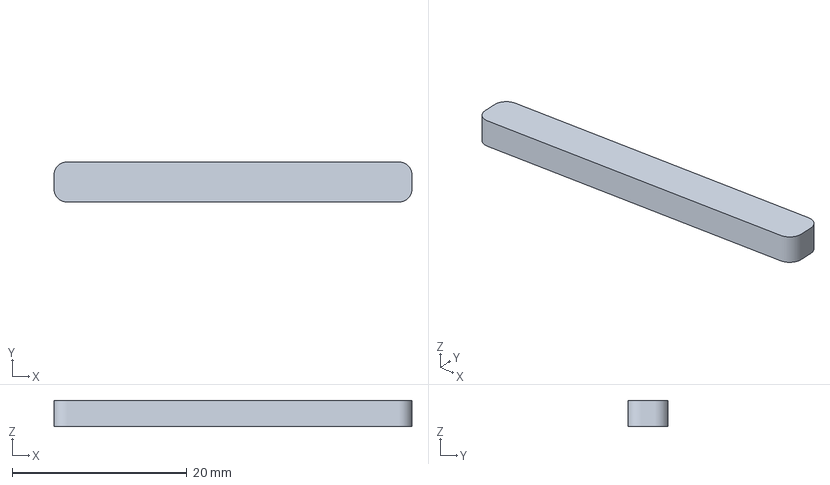
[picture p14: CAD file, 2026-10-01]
hardware/enclosure/stl/Безымянный5.FCStd
41.0 x 4.60 x 3.00 mm

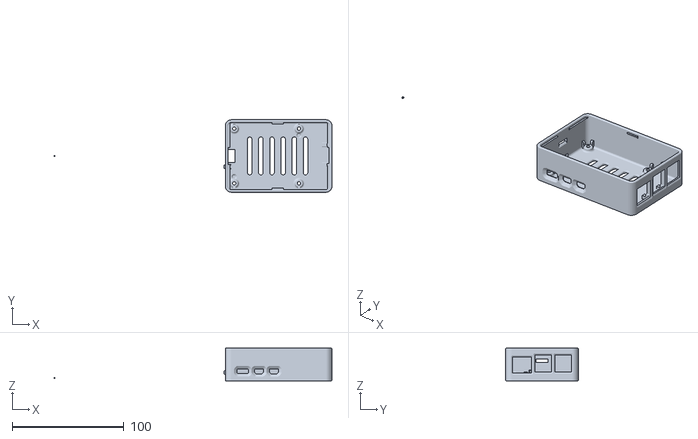
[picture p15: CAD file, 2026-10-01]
hardware/mount/_tmp/rt.stl
249.1 x 65.0 x 29.5

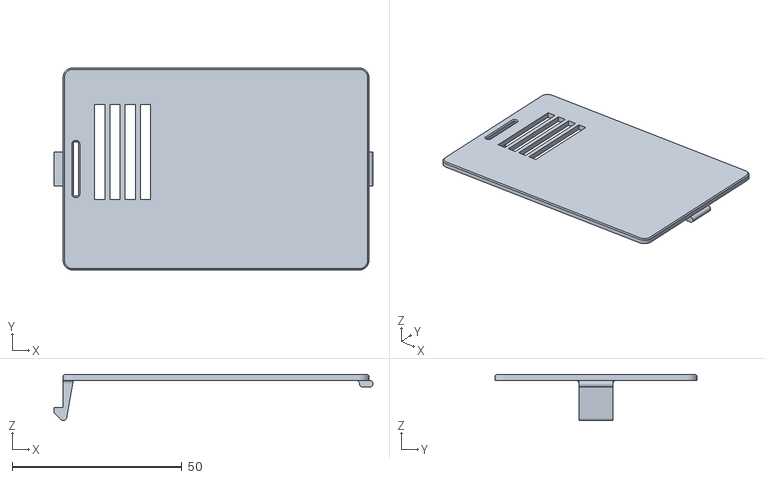
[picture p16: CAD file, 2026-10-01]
hardware/mount/cover_pigaze.stl
94.1 x 59.6 x 13.7

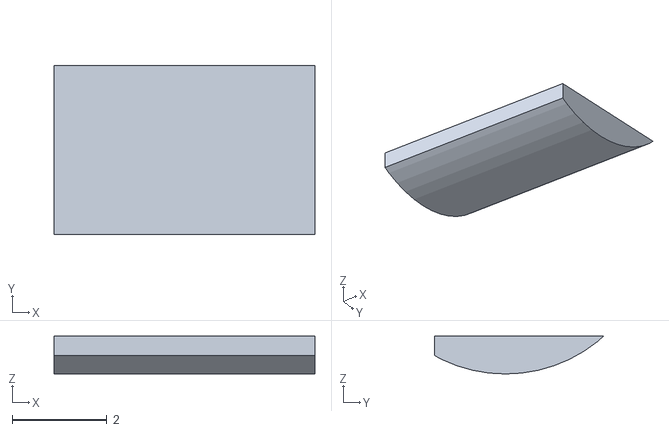
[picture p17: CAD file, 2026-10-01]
hardware/enclosure/out/chk/pwr_usbc.stl
5.50 x 3.57 x 0.8

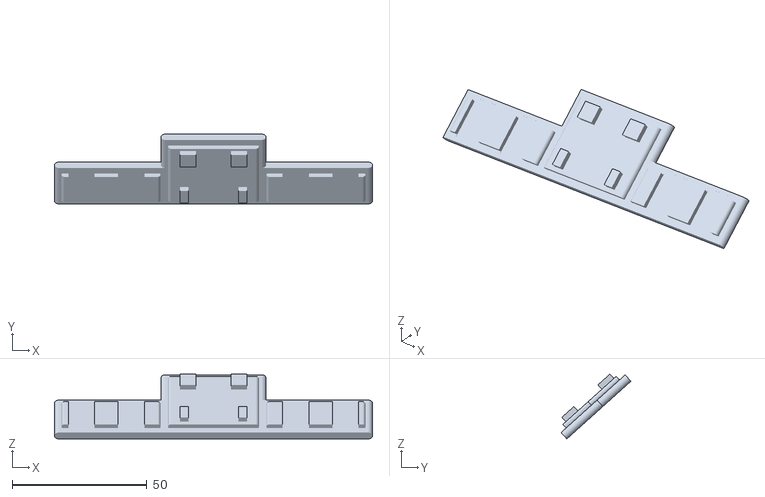
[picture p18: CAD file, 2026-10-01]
hardware/enclosure/out/pose/pose_barlid_t48.stl
118.0 x 25.9 x 24.1

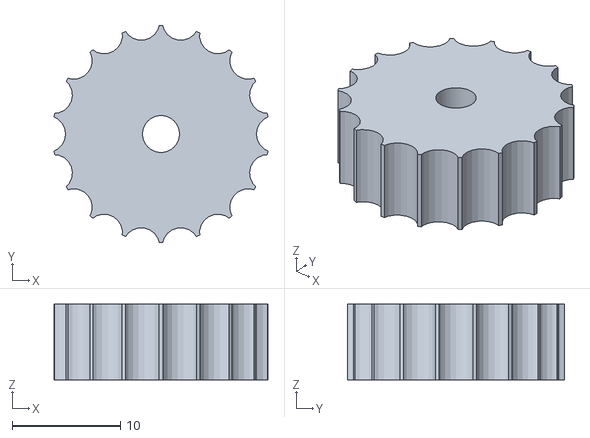
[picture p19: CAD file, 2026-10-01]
hardware/enclosure/stl/pigaze_knob.stl
19.7 x 20.0 x 7.00

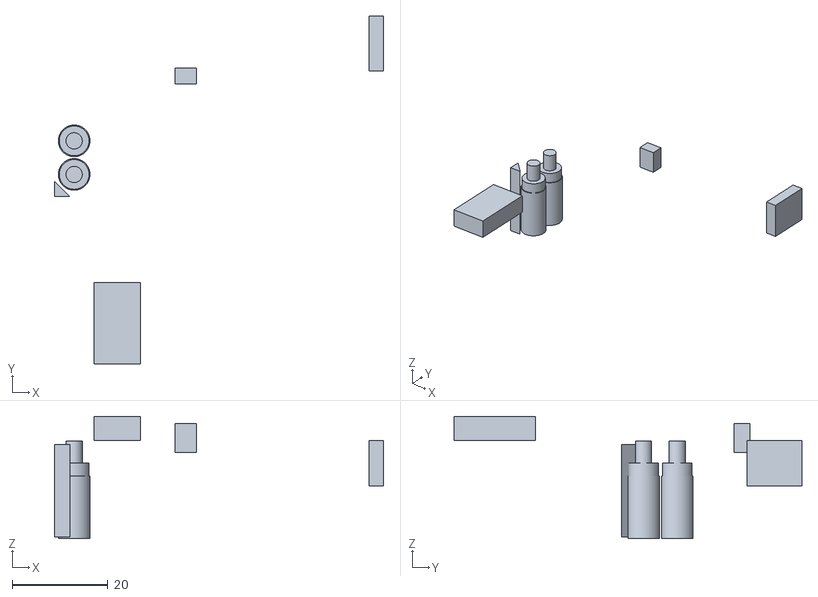
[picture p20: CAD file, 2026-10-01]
hardware/mount/_tmp/case_cut.stl
68.6 x 72.5 x 25.5

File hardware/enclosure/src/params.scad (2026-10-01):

// ============================================================================
//  Pi-Gaze / params.scad
//  Единый источник размеров. Всё остальное считается отсюда.
//  Единицы: мм.
//
//  ИСТОЧНИКИ ДАННЫХ:
//   [D] официальный механический чертёж Raspberry Pi 5
//       (datasheets.raspberrypi.com/rpi5/raspberry-pi-5-mechanical-drawing.pdf)
//   [M] замер пользователя штангенциркулем
//   [S] отраслевой стандарт разъёма
// ============================================================================

$fn = 56;

// ---------------------------------------------------------------- материалы
WALL      = 2.5;    // основная стенка
LID_TH    = 3.2;    // крышки (магнит 2 + потолок 0.4 + корка 0.8)
FIT       = 0.35;   // зазор бортиков крышек
CHAM      = 0.8;    // фаска-заход у проёмов разъёмов

// ------------------------------------------------------------------ магниты
// N42 диск 5 x 2 (заказаны)
MAG_D     = 5.0;
MAG_H     = 2.0;
MAG_FIT   = 0.2;
MAG_PD    = MAG_D + MAG_FIT;
MAG_CEIL  = 0.4;    // потолок над магнитом -> впаивается на паузе, снаружи не видно

// -------------------------------------------------------------- термовтулки
// ВАЖНО (правило heat-set): отверстие под втулку ВСЕГДА чуть МЕНЬШЕ её наружного
// (накатанного) диаметра — расплавленный пластик затекает в накатку и держит.
// Значения ниже — типовые рекомендованные отверстия; сверь с даташитом своих втулок.
// Втулки остаются ТОЛЬКО в креплении платы (M2.5). Всё прочее — гайки в карманах.
INS_M2_D  = 3.2;  INS_M2_L  = 4.0;
INS_M25_D = 3.5;  INS_M25_L = 5.0;   // <- крепление платы (отверстия Pi Ø2.7 => только M2.5)
INS_M3_D  = 4.0;  INS_M3_L  = 5.7;
INS_M5_D  = 6.4;  INS_M5_L  = 9.5;
INS_SLACK = 1.5;  // запас глубины под вытесненный пластик
BOSS_WALL = 2.0;  // мин. пластик вокруг втулки

// ------------------------------------------------------- гайки в карманах (M3)
// Единый крепёж корпуса — M3 винт + обычная M3-гайка в напечатанном кармане.
// ПРОВЕРЬ гайки: AF = размер под ключ (грани), TH = толщина.
NUT_M3_AF  = 5.5;   // M3 гайка, под ключ (DIN934/ISO4032)
NUT_M3_TH  = 2.4;   // M3 гайка, толщина
NUT_FIT    = 0.35;  // зазор карман/гайка (снуг, чтобы не проворачивалась)
SCREW_M3_D = 3.4;   // проход под винт M3 (+зазор)
SCREW_M25_D= 2.9;   // проход под винт M2.5

// =========================================================== RASPBERRY PI 5
// Плата 85 x 56 [D]. В корпусе стоит ребром CAM/DISP ВВЕРХ (поворот 90° CW),
// поэтому в координатах корпуса: X = 56 мм, Z = 85 мм.
PCB_X = 56;
PCB_Z = 85;
PCB_T = 1.6;

// Крепёж [D]: вдоль ребра 85 -> 3.5 и 61.5 ; вдоль ребра 56 -> 3.5 и 52.5.
// После поворота: X_b = Y_d ; Z_b = 85 - X_d
HOLE_X = [3.5, 52.5];
HOLE_Z = [23.5, 81.5];

// --- РАЗЪЁМЫ: позиции центров от угла платы (min X, min Z) --------------
// НИЗ (ребро 56, в чертеже правое): Ethernet, USB-стек, USB-стек [D]
P_BOTTOM = [10.2, 29.1, 47.0];
// ЛЕВО (ребро 85, в чертеже нижнее): USB-C, micro-HDMI 0, micro-HDMI 1
// (в чертеже 11.2/25.8/39.2 от левого края -> Z_b = 85 - X_d)
P_LEFT   = [73.8, 59.2, 45.8];

// --- РАЗЪЁМЫ: проём [ширина вдоль ребра, высота над платой] -------------
// ТЕЛА РАЗЪЁМОВ ИЗМЕРЕНЫ НА РЕАЛЬНОЙ 3D-МОДЕЛИ [S3D]
// (RASPBERRY_PI_5_WITH_ACTIVE_COOLER.stl, ~120k tri). Плата в модели центрирована
// в 0: нижняя медь A[-42.5,+42.5]=85, B[-28,+28]=56. Отображение в корпус
// (собственный поворот, кулер к крышке +Y, LAN/USB вниз -Z):  worldX = B ,
// worldZ = 48 - A. Центры разъёмов ПОДТВЕРДИЛИСЬ до 0.1 мм с чертёжными:
//   RJ45   центр worldX +17.8 (тело 15.90 x 13.68)
//   USB-A  центры worldX -1.1 / -19.0 (тело 13.25 x 15.80 — стек 2xUSB)
//   USB-C  центр worldZ 79.3 (тело 8.94 x 3.16)
//   HDMI   центры worldZ 64.7 / 51.3 (тело 6.50 x 2.88)
// ПРОЁМ = тело + ~0.7 мм суммарного зазора (0.35 на сторону) — снуг для FDM.
// Прежде C_USB высота 15.7 = телу 15.8 (нулевой зазор!) -> поднято до 16.5.
C_LAN    = [16.6, 14.4];   // 15.90 + 0.7  x  13.68 + 0.7
C_USB    = [14.0, 16.5];   // 13.25 + 0.75 x  15.80 + 0.7
C_USBC   = [ 9.6,  4.6];   //  8.94 + 0.66 x   3.16 + запас под штекер
C_HDMI   = [ 7.3,  4.4];   //  6.50 + 0.8  x   2.88 + запас под штекер
C_SD     = [13.0,  3.5];   // microSD, на нижней стороне у USB-C [S3D] (наружу НЕ выводим)

// --- прочее по плате
COOLER_H  = 15;   // Active Cooler над платой (VERIFY по STEP)
FAN_GAP   = 8;    // ОБЯЗАТЕЛЬНЫЙ зазор над турбинкой (иначе задыхается)
STAND_H   = 4.5;  // высота опор: зазор под пины кулера и нижние компоненты

// ============================================================ CAMERA MODULE 3
CAM_X = 25; CAM_Z = 24; CAM_T = 11.5;   // 25 x 24 x 11.5 [офиц. product brief]
CAM_FIT = 0.3;
CAM_LENS_D = 9;     // окно объектива
HOOD_H = 4;         // бленда (режет засветку от комнаты/экрана)

// ================================================================== ИК-ПОДСВЕТКА
// Vishay TSHA5203, 5 мм, 875 нм, ±12°, рабочий ток 20 мА
IR_WELL_D = 5.05;   // глухой колодец (press-fit, буртик не даёт провалиться)
IR_APER_D = 3.6;    // выходная апертура = светозащитный барьер к объективу
IR_SPACING = 44;    // база между диодами (dark-pupil: вынос от оси >= 15)

// ===================================================================== CH9329
// UART -> USB HID (мышь+клавиатура). ПРОВЕРЬ свой модуль.
CH_L = 34; CH_W = 15; CH_T = 9;

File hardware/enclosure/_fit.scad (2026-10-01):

include <src/params.scad>
include <src/lib.scad>
include <src/box.scad>
intersection(){ box_body(); translate([0,-9.8,48]) rotate([0,90,0]) import("C:/Users/bronl/Downloads/RASPBERRY_PI_5_WITH_ACTIVE_COOLER.stl", convexity=10); }

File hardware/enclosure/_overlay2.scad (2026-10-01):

include <src/params.scad>
include <src/lib.scad>
include <src/box.scad>
// корпус полупрозрачный, реальная плата сплошная -> видно, как разъёмы садятся в проёмы
color([0.6,0.6,0.62,0.22]) box_body();
color([0.1,0.5,0.9]) translate([0,-9.8,48]) rotate([0,90,0])
  import("C:/Users/bronl/Downloads/RASPBERRY_PI_5_WITH_ACTIVE_COOLER.stl", convexity=10);

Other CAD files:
hardware/enclosure/stl/pigaze_foot.stl
hardware/enclosure/out/chk/lens_bar.stl
hardware/enclosure/out/chk/cam_bar.stl
hardware/enclosure/out/pose/pose_knob.stl
hardware/enclosure/_overlay.scad
hardware/enclosure/_val.scad
hardware/enclosure/out/pose/pose_bar.stl
hardware/enclosure/out/pose/pose_bar_t20.stl
hardware/enclosure/out/pose/pose_bar_t30.stl
hardware/enclosure/out/pose/pose_bar_t38.stl
hardware/enclosure/out/pose/pose_bar_t48.stl
hardware/enclosure/out/pose/pose_barlid.stl
hardware/enclosure/out/pose/pose_barlid_t20.stl
hardware/enclosure/out/pose/pose_barlid_t30.stl
hardware/enclosure/out/pose/pose_barlid_t38.stl
hardware/enclosure/out/pose/pose_clamp.stl
hardware/enclosure/out/pose/pose_knob_y31.stl
hardware/enclosure/out/pose/pose_knob_y45.stl
hardware/enclosure/out/pose/pose_pad.stl
hardware/enclosure/pigaze_enclosure.scad
hardware/enclosure/src/bar.scad
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

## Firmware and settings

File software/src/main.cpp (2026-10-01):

// Pi-Gaze: IR camera -> eye tracker -> gaze model -> CH9329 -> PC cursor.
#include <signal.h>
#include <unistd.h>

#include <algorithm>
#include <atomic>
#include <cmath>
#include <cstdarg>
#include <cstdio>
#include <cstring>
#include <mutex>
#include <string>
#include <vector>

#include "pigaze/ch9329.hpp"
#include "pigaze/config.hpp"
#include "pigaze/controller.hpp"
#include "pigaze/debugview.hpp"
#include "pigaze/platform.hpp"
#include "pigaze/synth.hpp"
#include "pigaze/tracker.hpp"

using namespace pigaze;

namespace {

const char* kVersion = "pigaze 1.0";
std::atomic<bool> g_stop{false};
void onSignal(int) { g_stop = true; }

void logLine(const char* fmt, ...) {
    va_list ap;
    va_start(ap, fmt);
    std::vfprintf(stdout, fmt, ap);
    va_end(ap);
    std::fputc('\n', stdout);
    std::fflush(stdout);
}

std::string jsonEscape(const std::string& s) {
    std::string o;
    for (char ch : s) {
        const unsigned char c = static_cast<unsigned char>(ch);
        if (c == '"' || c == '\\') { o += '\\'; o += ch; }
        else if (c < 0x20) { char b[8]; std::snprintf(b, sizeof b, "\\u%04x", c); o += b; }
        else o += ch;
    }
    return o;
}

std::string fmt(const char* f, ...) {
    char buf[512];
    va_list ap;
    va_start(ap, f);
    std::vsnprintf(buf, sizeof buf, f, ap);
    va_end(ap);
    return buf;
}

bool parseCommand(const std::string& s, Command& c) {
    if (s == "calibrate") c = Command::Calibrate;
    else if (s == "toggle") c = Command::Toggle;
    else if (s == "pause") c = Command::Pause;
    else if (s == "resume") c = Command::Resume;
    else return false;
    return true;
}

class CommandQueue {
public:
    void push(Command c) { std::lock_guard<std::mutex> lk(m_); q_.push_back(c); }
    std::vector<Command> take() { std::lock_guard<std::mutex> lk(m_); std::vector<Command> r; r.swap(q_); return r; }

private:
    std::mutex m_;
    std::vector<Command> q_;
};

// HID when the UART is open, otherwise the cursor is simply not moved.
struct CursorSwitch : CursorOutput {
    HidMouse* hid = nullptr;
    void moveTo(const Vec2& n) override { if (hid) hid->moveTo(n); }
    void click() override { if (hid) hid->click(); }
};

// State shared with the HTTP thread.
struct Shared {
    std::mutex m;
    std::string status = "{}";
    Frame frame;
    FrameEyes eyes;
    bool haveFrame = false;
    double lastFrameRequest = -1e9;
};

const char kPage[] = R"HTML(<!doctype html>
<html lang="ru"><head><meta charset="utf-8"><meta name="viewport" content="width=device-width,initial-scale=1">
<title>Pi-Gaze</title>
<style>
body{font-family:system-ui,sans-serif;background:#111;color:#ddd;margin:16px}
button{font-size:16px;margin:4px 8px 4px 0;padding:8px 14px;border-radius:6px;border:1px solid #555;background:#222;color:#eee}
img{max-width:100%;border:1px solid #333;image-rendering:pixelated}
pre{background:#1a1a1a;padding:8px;overflow:auto;font-size:12px}
#line{font-size:18px}
</style></head><body>
<h2>Pi-Gaze</h2>
<div><button onclick="cmd('calibrate')">Калибровка</button><button onclick="cmd('toggle')">Пауза / продолжить</button></div>
<p id="line">…</p>
<img id="f" alt="ИК-кадр">
<p style="color:#888">Жёлтое — окна глаз, красное — зрачок, зелёное — блики ИК-диодов.</p>
<pre id="s"></pre>
<script>
const names={'need-calibration':'нужна калибровка','calibrating':'калибровка','tracking':'слежение','paused':'пауза'};
async function cmd(c){await fetch('/cmd/'+c,{method:'POST'});}
async function tick(){try{const s=await (await fetch('/status')).json();
document.getElementById('s').textContent=JSON.stringify(s,null,2);
let l='режим: '+(names[s.mode]||s.mode)+' · '+s.fps.toFixed(1)+' к/с';
if(s.mode==='calibrating')l+=' · точка '+s.calib.point+'/'+s.calib.points;
if(s.gaze.valid)l+=' · взгляд '+(s.gaze.x*100).toFixed(0)+'%, '+(s.gaze.y*100).toFixed(0)+'%';
document.getElementById('line').textContent=l;}catch(e){}}
function frame(){const i=document.getElementById('f');const n=new Image();
n.onload=()=>{i.src=n.src;setTimeout(frame,150)};n.onerror=()=>setTimeout(frame,1000);n.src='/frame.bmp?'+Date.now();}
setInterval(tick,500);tick();frame();
</script></body></html>
)HTML";

SynthEye synthEye(Vec2 c, double r) {
    SynthEye e;
    e.pupil = c;
    e.pupilR = r;
    e.irisR = std::max(2.4 * r, 16.0);
    e.eyeW = e.irisR * 1.9;
    e.eyeH = e.irisR * 0.95;
    e.glints = {c + Vec2(0.7, 3), c + Vec2(3.3, 3)};
    return e;
}

// Camera-free check of the live binary: synthetic face -> tracker, accuracy and timing.
int selftest(const AppConfig& cfg) {
    SynthScene s;
    s.width = cfg.width;
    s.height = cfg.height;
    const Vec2 L(cfg.width * 0.42 + 0.37, cfg.height * 0.46 + 0.61), R(L.x + cfg.width * 0.08 + 0.2, L.y + 2.3);
    s.eyes = {synthEye(L, 7), synthEye(R, 7)};
    s.spots.push_back({{cfg.width * 0.1, cfg.height * 0.2}, 14, 250});
    logLine("selftest: rendering a %dx%d synthetic face...", s.width, s.height);
    const Image img = renderScene(s);
    EyeTracker tr(cfg.tracker);
    double t0 = monotonicSeconds();
    FrameEyes fe = tr.process(img.view());
    const double searchMs = (monotonicSeconds() - t0) * 1000;
    if (!fe.eye[0].valid || !fe.eye[1].valid) { logLine("selftest: FAIL - eyes not found"); return 1; }
    t0 = monotonicSeconds();
    const int n = 50;
    for (int i = 0; i < n; ++i) fe = tr.process(img.view());
    const double trackMs = (monotonicSeconds() - t0) * 1000 / n;
    const double e0 = dist(fe.eye[0].pupil, L), e1 = dist(fe.eye[1].pupil, R);
    logLine("selftest: eye0 error %.2f px, eye1 error %.2f px, ipd %.1f px (true %.1f)", e0, e1, fe.ipdPx, dist(L, R));
    logLine("selftest: full-frame search %.1f ms, tracking %.2f ms/frame", searchMs, trackMs);
    const bool ok = e0 < 0.5 && e1 < 0.5 && fe.eye[0].hasGlint && fe.eye[1].hasGlint;
    logLine("selftest: %s", ok ? "OK" : "FAIL");
    return ok ? 0 : 1;
}

int snapshot(const AppConfig& cfg, const std::string& path) {
    RpicamSource cam(cfg);
    std::string err;
    if (!cam.start(err)) { logLine("camera: %s", err.c_str()); return 1; }
    Frame f;
    int got = 0;
    const double deadline = monotonicSeconds() + 15;
    while (got < 15 && monotonicSeconds() < deadline && !g_stop)   // let exposure settle
        if (cam.next(f, 500)) ++got;
    cam.stop();
    if (got == 0) { logLine("camera: no frames (is the camera connected? try: rpicam-hello --list-cameras)"); return 1; }
    if (!writePgm(path, f.view())) { logLine("cannot write %s", path.c_str()); return 1; }
    logLine("saved %dx%d frame to %s", f.width, f.height, path.c_str());
    return 0;
}

void usage() {
    std::puts("usage: pigaze [--config FILE] [--no-hid] [--calibrate]\n"
              "       pigaze --selftest | --snapshot FILE.pgm | --version\n"
              "  --config FILE    settings (default /etc/pigaze/pigaze.conf)\n"
              "  --no-hid         track and show on the debug page, never move the mouse\n"
              "  --calibrate      start with a calibration\n"
              "  --selftest       synthetic-image check of the tracker (no camera)\n"
              "  --snapshot FILE  save one camera frame (PGM) for tuning");
}

}  // namespace

int main(int argc, char** argv) {
    std::string cfgPath = "/etc/pigaze/pigaze.conf", snapPath;
    bool selftestMode = false, noHid = false, calibrateNow = false;
    for (int i = 1; i < argc; ++i) {
        const std::string a = argv[i];
        if (a == "--config" && i + 1 < argc) cfgPath = argv[++i];
        else if (a == "--snapshot" && i + 1 < argc) snapPath = argv[++i];
        else if (a == "--selftest") selftestMode = true;
        else if (a == "--no-hid") noHid = true;
        else if (a == "--calibrate") calibrateNow = true;
        else if (a == "--version") { std::puts(kVersion); return 0; }
        else { usage(); return a == "--help" ? 0 : 2; }
    }
    signal(SIGINT, onSignal);
    signal(SIGTERM, onSignal);
    signal(SIGPIPE, SIG_IGN);

    AppConfig cfg;
    std::vector<std::string> warnings;
    if (!loadConfigFile(cfgPath, cfg, warnings)) logLine("config %s not found: defaults", cfgPath.c_str());
    for (const std::string& w : warnings) logLine("config: %s", w.c_str());
    if (selftestMode) return selftest(cfg);
    if (!snapPath.empty()) return snapshot(cfg, snapPath);

    logLine("%s starting (%dx%d@%d)", kVersion, cfg.width, cfg.height, cfg.fps);
    EyeTracker tracker(cfg.tracker);
    SerialLink serial;
    HidMouse hid(serial);
    CursorSwitch cursor;
    const bool hidWanted = cfg.hidEnabled && !noHid;
    bool hidUsb = false, hidErrLogged = false;
    double nextHidTry = 0;

    Controller ctl(cfg.ctl, cursor);
    if (!ctl.loadCalibration()) logLine("no calibration yet: %s", cfg.ctl.autoCalibrate ? "it starts once your eyes are seen" : "double-press the power button");
    CommandQueue cmds;
    if (calibrateNow) cmds.push(Command::Calibrate);

    std::string err;
    PowerButton button;
    if (button.start([&cmds](ButtonEvent e) { cmds.push(e == ButtonEvent::Single ? Command::Toggle : Command::Calibrate); }, err))
        logLine("power button: single press = pause/resume, double press = calibrate");
    else logLine("power button: %s", err.c_str());
    ControlFifo fifo;
    if (!fifo.start("/run/pigaze/control", [&cmds](const std::string& line) {
            Command c;
            if (parseCommand(line, c)) cmds.push(c);
            else logLine("control: unknown command '%s'", line.c_str());
        }, err))
        logLine("control fifo: %s", err.c_str());

    Shared shared;
    DebugHttp http;
    const int shrink = std::max(1, (cfg.width + 799) / 800);
    if (cfg.httpPort > 0) {
        const bool ok = http.start(cfg.httpBind, cfg.httpPort,
            [&](const std::string& method, const std::string& path, std::string& type, std::string& body) {
                if (path == "/") { type = "text/html; charset=utf-8"; body = kPage; return true; }
                if (path == "/status") {
                    std::lock_guard<std::mutex> lk(shared.m);
                    type = "application/json";
                    body = shared.status;
                    return true;
                }
                if (path == "/frame.bmp") {
                    std::lock_guard<std::mutex> lk(shared.m);
                    shared.lastFrameRequest = monotonicSeconds();
                    if (!shared.haveFrame) return false;
                    const std::vector<uint8_t> bmp = encodeBmp(renderDebug(shared.frame.view(), shared.eyes, shrink, 3));
                    type = "image/bmp";
                    body.assign(bmp.begin(), bmp.end());
                    return true;
                }
                Command c;
                if (method == "POST" && path.rfind("/cmd/", 0) == 0 && parseCommand(path.substr(5), c)) {
                    cmds.push(c);
                    type = "application/json";
                    body = "{\"ok\":true}";
                    return true;
                }
                return false;
            },
            err);
        if (ok) logLine("debug page: http://%s:%d/", cfg.httpBind.c_str(), cfg.httpPort);
        else logLine("debug page: %s", err.c_str());
    }

    RpicamSource cam(cfg);
    double nextCamTry = 0, lastLog = monotonicSeconds(), lastStatus = 0, lastSnap = 0, fps = 0, prevT = 0;
    long nFrames = 0, nBoth = 0, nAny = 0;
    Frame frame;
    while (!g_stop) {
        const double now = monotonicSeconds();
        if (hidWanted && !serial.isOpen() && now >= nextHidTry) {
            nextHidTry = now + 5;
            if (serial.open(cfg.hidDevice, cfg.hidBaud, err)) {
                const auto q = ch9329::getInfo();
                serial.write(q.data(), q.size());
                usleep(150000);
                std::vector<uint8_t> rx(64);
                rx.resize(static_cast<size_t>(std::max(0, serial.read(rx.data(), rx.size()))));
                ch9329::Info info;
                if (ch9329::parseInfo(rx, info)) {
                    hidUsb = info.usbConnected;
                    logLine("CH9329 v%02x on %s, USB %s", info.version, cfg.hidDevice.c_str(),
                         info.usbConnected ? "connected to the PC" : "NOT connected to the PC");
                } else {
                    logLine("CH9329: no answer on %s @%d (check TX<->RX crossing, GND, 3.3 V levels)", cfg.hidDevice.c_str(), cfg.hidBaud);
                }
                cursor.hid = &hid;
                hidErrLogged = false;
            } else if (!hidErrLogged) {
                logLine("CH9329: %s (retrying every 5 s)", err.c_str());
                hidErrLogged = true;
            }
        }
        if (!cam.running() && now >= nextCamTry) {
            nextCamTry = now + 5;
            if (cam.start(err)) {
                std::string line;
                for (const std::string& a : cam.args()) line += a + " ";
                logLine("camera: %s", line.c_str());
            } else {
                logLine("camera: %s", err.c_str());
            }
        }
        if (!cam.next(frame, 200)) {
            if (!cam.running()) usleep(200000);            // camera down: wait, do not spin
            for (Command c : cmds.take()) ctl.command(c, now);
            for (const std::string& l : ctl.takeLog()) logLine("%s", l.c_str());
            continue;
        }

        const FrameEyes fe = tracker.process(frame.view());
        for (Command c : cmds.take()) ctl.command(c, frame.t);
        ctl.onFrame(frame.t, fe);
        for (const std::string& l : ctl.takeLog()) logLine("%s", l.c_str());

        ++nFrames;
        nBoth += fe.eye[0].valid && fe.eye[1].valid;
        nAny += fe.eye[0].valid || fe.eye[1].valid;
        if (prevT > 0 && frame.t > prevT) fps = fps > 0 ? 0.9 * fps + 0.1 / (frame.t - prevT) : 1 / (frame.t - prevT);
        prevT = frame.t;

        const ControllerStatus& st = ctl.status();
        if (now - lastStatus > 0.25) {
            lastStatus = now;
            std::string eyes;
            for (int k = 0; k < 2; ++k) {
                const EyeMeasurement& m = fe.eye[k];
                eyes += fmt("%s{\"tracked\":%s,\"valid\":%s,\"x\":%.2f,\"y\":%.2f,\"r\":%.2f,\"conf\":%.2f,\"glint\":%s,\"gx\":%.2f,\"gy\":%.2f}",
                            k ? "," : "", fe.tracked[k] ? "true" : "false", m.valid ? "true" : "false", m.pupil.x, m.pupil.y,
                            m.radius, m.confidence, m.hasGlint ? "true" : "false", m.glint.x, m.glint.y);
            }
            std::string js = "{";
            js += fmt("\"mode\":\"%s\",\"fps\":%.1f,\"calibrated\":%s,\"rms\":[%.4f,%.4f],", modeName(st.mode), fps,
                      st.calibrated ? "true" : "false", st.rms[0], st.rms[1]);
            js += fmt("\"calib\":{\"point\":%d,\"points\":%d,\"report\":\"", st.calibPoint, st.calibPoints) +
                  jsonEscape(st.lastCalibReport) + "\"},";
            js += fmt("\"gaze\":{\"valid\":%s,\"x\":%.4f,\"y\":%.4f},\"ipd\":%.1f,", st.gazeValid ? "true" : "false",
                      st.gaze.x, st.gaze.y, fe.ipdPx);
            js += "\"eyes\":[" + eyes + "],";
            js += fmt("\"hid\":{\"enabled\":%s,\"open\":%s,\"usb\":%s,\"sent\":%ld,\"dropped\":%ld},", hidWanted ? "true" : "false",
                      serial.isOpen() ? "true" : "false", hidUsb ? "true" : "false", hid.sent(), hid.dropped());
            js += fmt("\"camera\":{\"running\":%s,\"frames\":%ld,\"width\":%d,\"height\":%d}}", cam.running() ? "true" : "false",
                      cam.framesRead(), frame.width, frame.height);
            std::lock_guard<std::mutex> lk(shared.m);
            shared.status = js;
        }
        if (now - lastSnap > 0.15) {                     // debug picture only while someone watches
            std::lock_guard<std::mutex> lk(shared.m);
            if (now - shared.lastFrameRequest < 2.0 || !shared.haveFrame) {
                lastSnap = now;
                shared.frame.y = frame.y;
                shared.frame.width = frame.width;
                shared.frame.height = frame.height;
                shared.eyes = fe;
                shared.haveFrame = true;
            }
        }
        if (now - lastLog >= cfg.logIntervalS) {
            logLine("fps %.1f | eyes: any %ld%% both %ld%% | ipd %.0f px | %s | gaze %s | hid sent %ld dropped %ld",
                 fps, nFrames ? 100 * nAny / nFrames : 0, nFrames ? 100 * nBoth / nFrames : 0, fe.ipdPx, modeName(st.mode),
                 st.gazeValid ? fmt("%.2f,%.2f", st.gaze.x, st.gaze.y).c_str() : "-", hid.sent(), hid.dropped());
            lastLog = now;
            nFrames = nBoth = nAny = 0;
        }
    }
    logLine("stopping");
    cam.stop();
    http.stop();
    fifo.stop();
    button.stop();
    return 0;
}

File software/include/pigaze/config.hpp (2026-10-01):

// Pi-Gaze — configuration (key = value file, '#' comments, defaults for everything).
#pragma once
#include <string>
#include <vector>

#include "pigaze/controller.hpp"
#include "pigaze/tracker.hpp"

namespace pigaze {

struct AppConfig {
    // camera (rpicam-vid)
    int width = 2304, height = 1296, fps = 30;
    int shutterUs = 0;           // 0 = auto exposure
    double gain = 0;             // 0 = auto
    double lensPosition = 1.7;   // dioptres = 1 / distance in metres; < 0 = continuous autofocus
    std::string cameraExtra;     // appended to the rpicam-vid command line
    TrackerParams tracker;
    ControllerParams ctl;
    // CH9329
    bool hidEnabled = true;
    std::string hidDevice = "/dev/ttyAMA0";
    int hidBaud = 9600;
    // debug
    int httpPort = 8080;         // 0 = off
    std::string httpBind = "127.0.0.1";
    double logIntervalS = 5;

    AppConfig() { ctl.calibFile = "/var/lib/pigaze/calibration.txt"; }
};

// Applies "key = value" lines on top of `cfg`. Unknown keys / bad values -> warnings.
void parseConfig(const std::string& text, AppConfig& cfg, std::vector<std::string>& warnings);
bool loadConfigFile(const std::string& path, AppConfig& cfg, std::vector<std::string>& warnings);

}  // namespace pigaze

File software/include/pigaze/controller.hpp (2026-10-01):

// Pi-Gaze — the application logic: modes, calibration, cursor output. No I/O of its own.
#pragma once
#include <memory>
#include <string>
#include <vector>

#include "pigaze/calibration.hpp"
#include "pigaze/filter.hpp"
#include "pigaze/gaze.hpp"

namespace pigaze {

// Where cursor commands go (CH9329 on the Pi, a recorder in tests). Coordinates 0..1.
class CursorOutput {
public:
    virtual ~CursorOutput() = default;
    virtual void moveTo(const Vec2& n) = 0;
    virtual void click() = 0;
};

enum class Mode { NeedCalibration, Calibrating, Tracking, Paused };
const char* modeName(Mode m);

enum class Command { Toggle, Calibrate, Pause, Resume };

struct ControllerParams {
    CalibParams calib;
    double minCutoff = 0.6;      // One Euro, in screen fractions
    double beta = 2.0;
    double dCutoff = 1.0;
    bool autoCalibrate = true;   // start calibrating when eyes are seen and there is no calibration
    double autoCalibrateAfterS = 2.0;
    bool dwellClick = false;
    double dwellS = 1.2;
    double dwellRadius = 0.025;
    double gapResetS = 0.3;      // restart the filter after a gap in valid gaze (blink, glance away)
    std::string calibFile;       // empty = do not persist
};

struct ControllerStatus {
    Mode mode = Mode::NeedCalibration;
    bool gazeValid = false;
    Vec2 gaze;                   // filtered, 0..1
    int calibPoint = 0, calibPoints = 0;
    std::string lastCalibReport;
    double rms[2] = {0, 0};
    bool calibrated = false;
};

class Controller {
public:
    Controller(const ControllerParams& p, CursorOutput& out);
    bool loadCalibration();                     // from p.calibFile
    void command(Command c, double t);
    void onFrame(double t, const FrameEyes& eyes);
    Mode mode() const { return mode_; }
    const ControllerStatus& status() const { return status_; }
    const GazeModel& model() const { return model_; }
    std::vector<std::string> takeLog();         // human-readable events since the last call

private:
    void startCalibration(double t);
    void finishCalibration(double t);
    void play(const std::vector<Vec2>& path, double t, double stepS);
    void log(const std::string& s) { log_.push_back(s); }

    ControllerParams p_;
    CursorOutput& out_;
    Mode mode_ = Mode::NeedCalibration;
    Mode beforeCalib_ = Mode::NeedCalibration;
    GazeModel model_;
    std::unique_ptr<CalibrationSession> session_;
    OneEuro2 filter_;
    Dwell dwell_;
    double lastValidT_ = -1e9;
    double eyesSinceT_ = -1;
    bool autoTried_ = false;
    struct Anim { std::vector<Vec2> path; double t0 = 0, step = 0; } anim_;
    ControllerStatus status_;
    std::vector<std::string> log_;
};

}  // namespace pigaze

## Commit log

2026-09-11 docs: pupil-detection implementation plan (8 TDD tasks)
    Camera-independent units (config, pupil detector, telemetry, golden
    gate, YuNet) first and testable on a Linux dev box; camera bring-up
    and app loop on the Pi. TDD, commit per green step.
2026-10-01 feat: hardware enclosure, C++ software, deploy scripts and docs
    Add hardware/ (OpenSCAD/CadQuery enclosure, mounts, STL/renders),
    software/ (C++ gaze tracker core, Linux platform layer, tests, deploy),
    README, .gitattributes and the software design spec. Update pupil
    detection plan/spec. Keep the Wi-Fi network-config out of git.
    [_fit.scad, _overlay.scad, _overlay2.scad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]
